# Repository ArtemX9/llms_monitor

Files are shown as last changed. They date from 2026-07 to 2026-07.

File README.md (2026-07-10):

# Claude Monitor

An ESP32-based desk display that shows real-time Claude Code and Grok API usage stats on a 320×240 ILI9341 TFT screen.

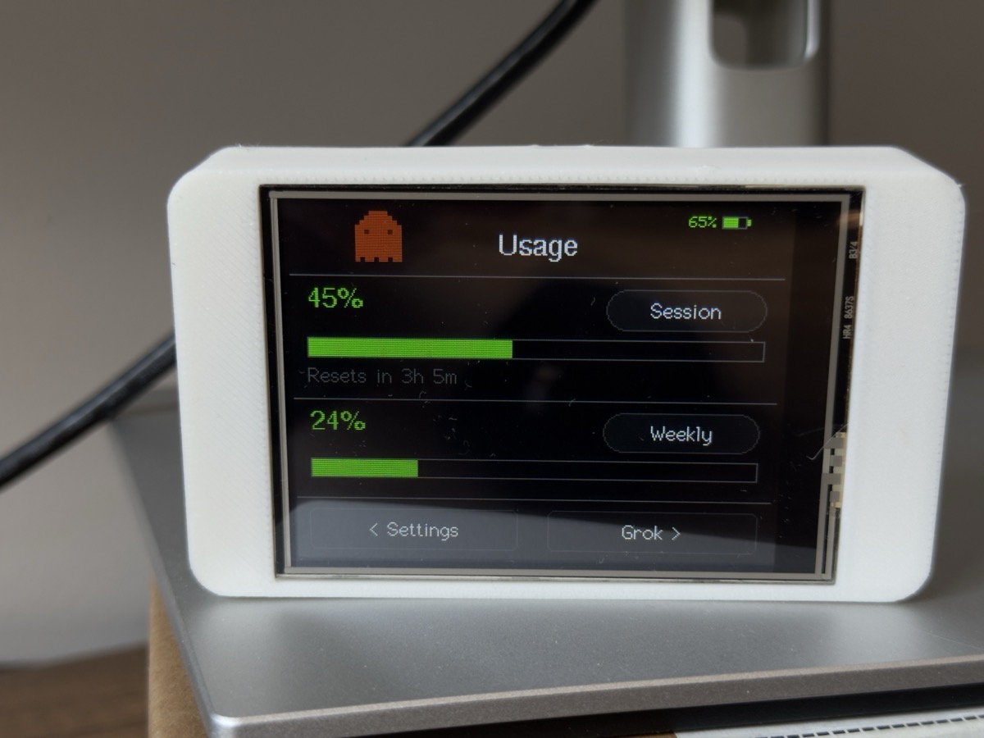
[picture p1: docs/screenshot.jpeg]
Device showing Claude Code session and weekly usage


## What it does

- **Claude screen** — session usage %, weekly usage %, and minutes until reset
- **Grok screen** — usage % and time until the billing period resets
- **Settings screen** — backlight brightness, refresh interval (30 / 60 / 120 s), reboot button
- Swipe left/right anywhere on the screen to navigate between the three screens
- Fetches data from a local proxy server over WiFi; auto-reconnects and restarts after 5 consecutive failures

## Hardware

| Component | Detail |
|---|---|
| MCU | ESP32 |
| Display | ILI9341 320×240 SPI TFT |
| Touch | XPT2046 resistive |
| Backlight | PWM-controlled via GPIO14 |

### Wiring

| Signal | GPIO |
|---|---|
| TFT CS | 15 |
| TFT DC | 21 |
| TFT RST | 4 |
| TFT MOSI | 23 |
| TFT SCLK | 18 |
| TFT MISO | 19 |
| Touch CS | 5 |
| Backlight | 14 |
| Status LED | 2 |

## Software

Built with [PlatformIO](https://platformio.org/) and the Arduino framework.

**Dependencies** (declared in `platformio.ini`, installed automatically):
- [TFT_eSPI](https://github.com/Bodmer/TFT_eSPI) — display + touch driver
- [ArduinoJson v7](https://arduinojson.org/) — JSON parsing

## Build & flash

```bash
pio run -t upload
pio device monitor       # 115200 baud
```

Prebuilt firmware binaries (for flashing with `esptool` instead of building from source) are published on the [Releases page](../../releases) for each tagged version.

## Data source

The device fetches from a local proxy server (default `http://192.168.2.131:3000`). The proxy should return:

```json
{
  "claude": { "session_pct": 43, "weekly_pct": 9, "reset_min": 240 },
  "grok":   { "usage_pct": 12, "reset_min": 44640 }
}
```

Note: on flat-rate Grok plans (e.g. X Premium), `usage_pct` reads `0` regardless of actual usage — the upstream billing endpoint only meters pay-as-you-go/on-demand usage, not flat-rate quota.

WiFi credentials and proxy URL are set at the top of `src/main.cpp`.

## Case (CAD)

```
cad/
  case.scad         — OpenSCAD source for the 3D-printed enclosure
  stl/
    case_body.stl    — exported body, ready to slice
    case_lid.stl      — exported lid, ready to slice
```

Edit `case.scad` in [OpenSCAD](https://openscad.org/) and re-export the STLs after any change.

## Project structure

```
src/
  Config.h          — pin and PWM channel defines
  Types.h           — UsageData, AppState, Event
  DataFetcher.h/cpp — WiFi management and HTTP fetch
  Renderer.h/cpp    — TFT drawing (pure, stateless)
  TouchRouter.h/cpp — touch input, returns Event enum
  main.cpp          — credentials, globals, setup(), loop()
```

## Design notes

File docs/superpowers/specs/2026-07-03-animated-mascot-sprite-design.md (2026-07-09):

# Animated mascot sprite — design

## Context

The Claude screen header currently blits a single static 10-col × 12-row pixel-art sprite
(`SPR` in `Renderer.cpp`) inline as part of `drawClaude()`. This design
replaces it with a small library of characters, each with a 4-frame idle animation, one of
which is randomly selected and shown at a time, re-rolled periodically. Two of the
characters additionally patrol back and forth across the header.

Scope: **Claude screen only.** The Grok screen keeps its current text-only header.

## Data format — `src/SpriteData.h`

Pure data, no logic. Same `0/1/2` grid convention as today (`0` = transparent, `1` = body
color, `2` = accent color) — one shared color pair for all characters (`body` = orange,
`dark` = darker orange, same values `drawClaude()` uses today).

Each character is 4 frames of a 12-row × 10-col `PROGMEM` grid, plus a movement type:

```cpp
enum class SpriteMotion { STATIC, PATROL };

struct Character {
  const uint8_t (*frames)[12][10]; // 4 frames
  SpriteMotion motion;
};
```

**Four characters for v1** (grids as previewed and approved in the visual companion
session):

1. **Bot** (today's sprite, reworked into an idle loop) — `STATIC`. Frames cycle
   eyes-open/neutral-smile → blink → eyes-open/wide-smile → eyes-open/neutral-smile.
2. **Ghost** — `PATROL`. Floaty body, wavy two-state tail alternating each frame.
3. **Cat** — `STATIC`. Pointy ears, blinking eyes (blink on frame 3 of 4).
4. **Robot** — `PATROL`. Single eye band that scans across 3 horizontal positions
   (center → left → center → right) over its 4 frames.

Adding a 5th character later means appending 4 grids + one `Character` table entry — no
other code changes.

## `src/AnimatedSprite.h/.cpp`

New class owning all animation state. Does **not** hold a `TFT_eSPI` reference — `draw()`
takes it as a parameter, so there's no constructor-order dependency with `Renderer` (unlike
`TouchRouter`, which does need to capture `renderer.tft()`).

```cpp
class AnimatedSprite {
public:
  void tick(unsigned long nowMs);      // advance frame/position; cheap no-op most calls
  bool needsRedraw() const;            // true if tick() changed frame or position since last draw()
  void draw(TFT_eSPI& tft);            // erase sprite lane + redraw at current frame/position
private:
  int _character;                      // current index into the character table
  int _frame;                          // 0-3
  unsigned long _lastFrameMs;
  unsigned long _lastRerollMs;
  enum class Phase { Idle, Entering, AtLeft, ToTitle, AtTitle, ToLeft } _phase;
  unsigned long _phaseStartMs;
  float _x;                            // current draw x
  void reroll(unsigned long nowMs);    // pick new random character via esp_random(), reset phase
};
```

### Timing constants

| Constant | Value | Notes |
|---|---|---|
| Frame rate (idle animation) | 4 fps (250 ms/frame) | applies to all characters, moving or not |
| Reroll interval | 5 min | `esp_random()`, no seeding needed on ESP32 |
| Entrance (off-screen → left spot) | 5 s, ease-in-out | `PATROL` characters only, plays once per reroll |
| Pause at each stop | 2 s | left spot and title spot |
| Travel leg (left ↔ title) | 3 s, ease-in-out | repeats forever after the one-time entrance |
| Resting/left x | 5 px (today's sprite position) | |
| Title-side x | tuned on hardware, ~90–100 px | must clear the "Usage" title's left edge — exact value picked during implementation by checking on the physical panel |
| Robot hop step size | ~6 px per step, alternating −3px y bounce | quantizes the eased position, doesn't change its own timing |

`STATIC` characters (Bot, Cat) skip all `Phase` states except `Idle`: `_x` is pinned to the
resting x for the character's whole lifetime; only the frame timer runs.

On reroll, `_phase` resets to `Entering` (for `PATROL`) or `Idle` (for `STATIC`) regardless
of whether the newly-picked character happens to match the previous one — no special-casing
for repeats.

## Redraw strategy

Every time `tick()` reports a change, `draw()`:
1. `fillRect(0, 0, 140, 44, TFT_BLACK)` — clears a fixed "sprite lane" spanning the header
   strip left of the "Usage" title. Cheap, and avoids tracking the previous frame's exact
   bounding box.
2. Blits the current character/frame's grid at `(_x, 2)`.

No `fillScreen()` — the rest of the header (title text, divider line) is never touched by
sprite ticks. Full-screen redraws still happen exactly where they do today (screen switch,
data fetch → `drawClaude()`), and `drawClaude()` calls `_sprite.draw()` once as part of its
existing full redraw.

## Integration

- `Renderer` gains `AnimatedSprite _sprite;` and a public `void tickSprite();`:
  ```cpp
  void Renderer::tickSprite() {
    _sprite.tick(millis());
    if (_sprite.needsRedraw()) _sprite.draw(_tft);
  }
  ```
- `drawClaude()` replaces its inline `SPR` blit loop with `_sprite.draw(_tft)`.
- `main.cpp`'s `loop()` calls `renderer.tickSprite()` unconditionally on every iteration
  when `state.screen == 0` — no external rate limiting needed, since `tick()` internally
  no-ops unless ~80ms have elapsed (settles to ~10Hz for position smoothness, independent
  of the 4fps frame rate and 5min reroll timer, both tracked by their own timestamps
  inside `AnimatedSprite`).
- This is a new, independent timer alongside the existing WiFi-fetch timer in `loop()` —
  it does not touch `state.needsFullRedraw` or the fetch cadence.

## Testing

No existing automated test harness in this repo (embedded/visual firmware). Verification
is manual, on the physical device after flashing: confirm each character's idle animation,
confirm Ghost/Robot patrol motion and pacing match what was approved in the visual
companion mockup, confirm reroll picks a new character every ~5 min, and confirm the
sprite lane redraw doesn't clip or flicker the "Usage" title.

## Out of scope (v1)

- Grok screen sprite/header (stays text-only).
- Per-character color variation (all characters share one body/accent color pair).
- More than 4 characters.
- Full off-screen exit-and-re-enter on every patrol cycle (only the very first appearance
  plays the off-screen entrance; subsequent cycles bounce between the left and title spots
  without leaving the screen).

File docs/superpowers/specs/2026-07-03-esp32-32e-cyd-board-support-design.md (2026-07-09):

# ESP32-32E CYD Board Support

## Goal

Add support for a second physical board — a "3.2 ESP32-32E 240x320 Resistance
Touch" all-in-one display module (Sunton/CYD-family clone; manufacturer
Shenzhen Hong Shu Yuan Technology; serial H06201; screen marked "HR4 8637S
B3/4") — on a dedicated branch, `esp32-32e-cyd`.

This board integrates the ESP32, TFT, and touch controller on one PCB with a
fixed pin layout, unlike the current hardware (a bare ILI9341 module
hand-wired to an ESP32 dev board on arbitrary pins).

## Hardware facts

Sourced from LCD Wiki's page for this exact board
(`3.2inch_ESP32-32E_Display`); to be verified empirically once flashed since
clone boards sometimes disagree with vendor docs.

| Function | Pin |
|---|---|
| TFT driver | **ST7789P3** (not ILI9341 — this is the main change) |
| TFT CS | IO15 |
| TFT DC | IO2 |
| TFT RST | EN (no dedicated GPIO — tied to chip reset) |
| TFT MOSI | IO13 |
| TFT SCLK | IO14 |
| TFT MISO | IO12 |
| TFT Backlight | IO27 (active high) |
| Touch (XPT2046) CS | IO33 |
| Touch IRQ | IO36 |
| Touch MOSI/SCLK/MISO | shared with TFT bus (13/14/12) |
| microSD CS/MOSI/SCLK/MISO | 5/23/18/19 (separate VSPI bus) — unused by this project, left unconfigured |

Two pins used by the current board's `Config.h` are unavailable here because
the display claims them:

- **GPIO2** — currently the status LED pin; on this board it's the TFT DC line.
- **GPIO14** — currently the backlight PWM pin; on this board it's the TFT SCLK line. The new board has its own dedicated backlight pin (IO27), so this isn't a "find a free pin" problem, just a different constant.

## Scope of changes (on the `esp32-32e-cyd` branch)

This branch is a direct hardware swap, not a multi-board codebase. No
`#ifdef`s, no second PlatformIO environment — `platformio.ini` and
`Config.h` are edited in place for this board, mirroring how the branch
itself already isolates the two hardware targets.

1. **`platformio.ini`**: replace `-DILI9341_DRIVER` and the old pin flags
   with `-DST7789_DRIVER` (or the exact TFT_eSPI macro name for ST7789P3)
   and the pin table above. `TFT_WIDTH`/`TFT_HEIGHT` stay 240×320. Rotation
   (currently `3` for landscape) and the touch-mirroring math documented in
   `CLAUDE.md` are specific to the old board's physical wiring and must be
   re-derived empirically on this board — not something to guess at in this
   design.

2. **`Config.h`**: drop `LED_PIN`. Change `TFT_BL_PIN` to 27.
   `BL_CHANNEL`/`BL_FREQ`/`BL_RES` unchanged.

3. **Replace the physical status LED with an on-screen indicator**, keeping
   the existing architecture's separation of concerns intact:
   - `DataFetcher::connect()` and `ensureWifi()` currently blink a GPIO
     directly inside their blocking wait loops. They will instead accept an
     optional tick callback (function pointer), invoked once per ~250ms
     blink tick and once more with the final connected/failed state.
     `DataFetcher` still does not touch the display or any drawing code —
     it only reports state through the callback.
   - `Renderer` gains a small method (e.g. `drawWifiIndicator(bool on)`)
     that draws or clears a small dot in a fixed screen corner without a
     full redraw.
   - `main.cpp` wires the two together: it passes a lambda to
     `DataFetcher` that calls `renderer.drawWifiIndicator(...)`, respecting
     the existing `ledEnabled` state.
   - The Settings screen's existing "LED" toggle (added in the most recent
     commit) is repointed to enable/disable this on-screen indicator instead
     of a physical GPIO. No UI relabeling needed — same toggle, same
     semantics from the user's point of view ("show a connection heartbeat
     indicator or not").

4. **`CLAUDE.md`**: once the board is flashed and the real rotation/touch
   quirks are known, add a short section documenting this board alongside
   the existing hardware-quirks section, so future work on this branch
   doesn't rediscover them.

## Out of scope

- No dual-board / shared-codebase support — this is a hardware-swap branch.
- No use of the onboard microSD slot, speaker, or I2C header — not needed by
  this project.
- Exact rotation value and touch-axis mirroring are left as "verify on
  hardware" — cannot be determined from docs alone, per this project's own
  documented experience with the current board's touch quirk.

## Testing / validation plan

After flashing to the physical board:

1. Confirm the display draws with correct colors and no inversion (ST7789
   panels frequently need a color-inversion flag that ILI9341 doesn't).
2. Confirm touch coordinates map correctly to visual positions on all
   screens; re-derive any mirroring math and update `TouchRouter.cpp` and
   `CLAUDE.md`.
3. Confirm backlight PWM works via GPIO27 across the brightness range.
4. Confirm the on-screen WiFi indicator behaves like the old LED did:
   blinks while connecting, solid when connected, off when disabled via the
   Settings toggle.

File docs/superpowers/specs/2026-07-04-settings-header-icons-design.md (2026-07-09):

# Settings screen: header icon buttons for Reboot and LED

## Problem

The Settings screen currently shows Reboot and LED-toggle as full-width labeled
cards in a body row (`drawOutlineCard` at y180-212, see
[Renderer.cpp:326-328](../../../src/Renderer.cpp#L326)). The goal is to move both
into small icon-only buttons in the header, freeing that body row, and to make
Reboot safer against accidental taps now that it sits right next to the title
rather than at arm's length at the bottom of the screen.

## Non-goals

- No change to Claude or Grok screens.
- No change to Brightness or Refresh cards' layout, coordinates, or behavior.
- No new `Event` enum value — `Event::Reboot` and `Event::ToggleLed` are reused;
  arm/confirm timing is `main.cpp`'s concern, not `TouchRouter`'s.
- No persistence of reboot-armed state across screen switches or reboots — it's
  transient UI state, reset to disarmed whenever the Settings screen isn't the
  active screen or the 2-second window lapses.

## Header layout

Header region is y=0 to y=44 (Brightness card starts at y=44, unchanged).

| Element | Position | Notes |
|---|---|---|
| Reboot icon button | `(6, 6, 32, 32)` rounded rect, radius 6 | Outline style: `colorCardBg()` fill, `colorDestructive()` border (normal state) |
| LED icon button | `(44, 6, 32, 32)` rounded rect, radius 6 | Filled bulb glyph, no separate border needed — the fill color itself is the state signal |
| "SETTINGS" title | `x=86, y=8` (was `x=10`) | Same `TITLE_FONT`, same y — only x moves to clear the icons |
| WiFi status dot | `(310, 8)` | Unchanged |

Gap between the two icon buttons: 6px+32px=38, +6px gap = LED starts at x=44. Both fit comfortably before the title at x=86.

## Icon glyphs

Both drawn from `TFT_eSPI` primitives — no icon font or image assets.

**Reboot (refresh/restart glyph):** a broken ring drawn with `_tft.drawArc(cx, cy, r, ir, startAngle, endAngle, fgColor, bgColor, true)` spanning roughly 270° (e.g. 45°→315°, leaving a 90° gap), plus a small filled triangle arrowhead at the arc's leading end (`_tft.fillTriangle(...)`, three points computed from the end angle) to imply direction. Center at the button's center `(22, 22)` relative to button origin, i.e. absolute `(6+16, 6+16) = (22, 22)`; ring radius `r=9`, inner radius `ir=6` (3px-thick ring, comfortably legible at this size).

- Normal (disarmed) state: button background `colorCardBg()`, border `colorDestructive()`, glyph drawn in `colorDestructive()`.
- Armed state (after first tap): button background fills solid `colorDestructive()` (no border needed), glyph redrawn in a contrasting color (`TFT_WHITE`) so it stays visible against the red fill.

**LED (lamp glyph):** a simple bulb shape — a filled circle (the bulb's glass) plus a small filled rectangle beneath it (the base/screw), both drawn in the same single fill color representing state, no separate dot:
- On: `colorLedOn()` — new helper, `color565(34, 197, 94)` (matches the mockup's green, distinct from the general UI accent indigo since this is a literal on/off traffic-light signal, not a "selected" state)
- Off: `colorDestructive()` (red) — reusing the existing destructive-red helper since both represent "off"/negative state colors in this palette

Bulb circle: center `(22, 22)` relative to button origin (absolute `(62, 22)`), radius 8. Base rectangle: `4px` wide, `3px` tall, centered below the circle.

## Body layout after removing the old LED+Reboot row

- Brightness card: unchanged, `drawCard(6, 44, 308, 56)`.
- Refresh card: unchanged, `drawCard(6, 110, 308, 58)`.
- The old row at y180-212 (`drawLedToggle` + the Reboot `drawOutlineCard` call in `drawSettings`) is deleted entirely. The vertical space from y=168 (Refresh card's bottom edge) to the nav buttons' new top edge (y=209, see below) is simply empty — no new element fills it.

## Nav buttons resize

`< Grok` / `Claude >` (`drawButton` calls in `drawSettings`, currently `(8, 216, 142, 22)` and `(170, 216, 142, 22)`):

- Width stays `142` (already uses 304 of the 320px screen width across both buttons; ×1.3 would overflow off-screen).
- Height scales ×1.3: `22 → 29`.
- New y: `209` (was `216`) — keeps the same ~2px bottom margin as before (`209+29=238`, screen height is 240, same bottom margin the old buttons had at `216+22=238`).
- New calls: `drawButton(8, 209, 142, 29, "< Grok", f, b, TFT_WHITE)` and `drawButton(170, 209, 142, 29, "Claude >", f, b, TFT_WHITE)`.

This is the *only* change to Claude/Grok-shared code in this spec — `drawButton`'s signature and body are untouched; only the call-site arguments in `drawSettings` change.

## Reboot confirm-tap mechanics

New `AppState` field: `unsigned long rebootArmedAt = 0;` (`0` means disarmed), declared alongside the struct's other fields in [Types.h](../../../src/Types.h#L14), owned exclusively by `loop()` per existing convention.

Flow, entirely in `main.cpp`'s `loop()`:

1. Tap on the reboot icon always emits `Event::Reboot` (no new `Event` value).
2. On `Event::Reboot`:
   - If `state.rebootArmedAt != 0 && millis() - state.rebootArmedAt < 2000`: this is the confirming second tap — proceed exactly as today (`renderer.showRebooting(); delay(300); ESP.restart();`).
   - Else: this is the arming first tap — set `state.rebootArmedAt = millis();` and call a new `renderer.updateRebootIcon(true)` to redraw the icon in its armed (solid red) visual.
3. Every `loop()` iteration, if `state.screen == 2 && state.rebootArmedAt != 0 && millis() - state.rebootArmedAt > 2000`: auto-disarm — set `state.rebootArmedAt = 0;` and call `renderer.updateRebootIcon(false)` to revert the icon to its normal outline visual.
4. On `Event::NavForward`/`Event::NavBack` while `state.screen == 2` (i.e. leaving Settings): reset `state.rebootArmedAt = 0;` silently — no redraw call needed since `switchTo()` already does a full redraw of the destination screen.

No debounce changes needed in `TouchRouter` — its existing 300ms `_lastTouch` debounce (unrelated to this 2-second arm window) continues to work exactly as today; the two taps needed to confirm a reboot are two separate, individually-debounced touch events.

## TouchRouter changes

Two new zones added to `TouchRouter::poll()`'s `screen == 2` branch, checked before the existing zones (they occupy y=6-38, below any other zone's range):

```cpp
if (y >= 6 && y <= 38) {
  if (x >= 6  && x <= 38) return Event::Reboot;
  if (x >= 44 && x <= 76) return Event::ToggleLed;
  return Event::None;
}
```

The old zone check for the y180-212 row (LED at x10-155, Reboot at x165-310) is deleted entirely — that row no longer has any controls.

The nav-row check moves from `y > 213` to `y > 204` (buffer above the new button top edge at y=209; still well below the Refresh card's bottom edge at y=168 and the interval buttons' zone which ends at y=162, so no ambiguity with the now-empty gap between them).

## Renderer changes

- `drawSettings`: header title x moves to 86; calls a new private `drawRebootIcon(false)` and a rewritten `drawLedToggle(ledEnabled)` (now draws the icon button, not the old text card) at their header positions instead of the old body-row `drawOutlineCard`/`drawLedToggle` calls; nav button calls updated to the new y=209, h=29 coordinates.
- New private `void drawRebootIcon(bool armed)` — draws the button background/border per the armed/disarmed states above, plus the arc+arrowhead glyph.
- New public `void updateRebootIcon(bool armed)` — thin wrapper calling `drawRebootIcon(armed)`, mirroring the existing `updateLedToggle` pattern (declared in `Renderer.h`'s public section alongside `updateLedToggle`).
- `drawLedToggle(bool ledEnabled)` rewritten to draw the bulb glyph (filled circle + base rect) at its new header position and size, using `colorLedOn()`/`colorDestructive()` instead of the old outline-card-with-text approach. Its existing public wrapper `updateLedToggle` needs no signature change — it already just calls `drawLedToggle`.
- New private `uint16_t colorLedOn()` color helper alongside the existing `colorAccent()`/`colorDestructive()`/etc. in the "Shadcn-style palette" block.
- `drawOutlineCard` (added for the previous restyle) becomes unused by `drawSettings` once this change lands. It's still a generically useful helper (rounded card + centered label) — leaving it in place is fine (YAGNI cuts against inventing a reason to delete a small, still-coherent, still-compiling helper it just isn't used by anymore, not against harmless unused code); if a future task never finds a use for it, removing it then is a one-line cleanup, not a design concern for this spec.

## Files changed

- `src/Types.h` — add `rebootArmedAt` field to `AppState`.
- `src/TouchRouter.cpp` — add header icon zones, remove old y180-212 zone, adjust nav-row y threshold.
- `src/Renderer.h` — add `updateRebootIcon` to the public section, `drawRebootIcon` and `colorLedOn` to the private section.
- `src/Renderer.cpp` — all drawing changes described above.
- `src/main.cpp` — reboot arm/confirm/auto-disarm logic in `loop()`.

No changes to `src/DataFetcher.*`, `src/AnimatedSprite.*`, `src/SpriteData.h`, `src/Config.h`, or the Claude/Grok screens beyond the shared `drawButton` call-site coordinate change already covered above.

## Testing

Same as the prior restyle work — no automated test harness exists for `Renderer`
or hardware touch/timing behavior. Verification is `pio run` compiling cleanly,
then hardware flash + manual verification:

- Both header icons render at the correct position/size, don't visually collide
  with the shifted title or the WiFi dot.
- Tapping the LED icon toggles it on/off exactly as before (just via the new
  icon instead of the old text card), with the bulb filling green/red correctly.
- Tapping the reboot icon once arms it (fills solid red); tapping it again
  within 2 seconds actually reboots the device; waiting past 2 seconds without
  a second tap reverts it to the normal outline automatically.
- Navigating away from Settings while armed and back again shows the icon
  disarmed (normal outline), not stuck in the armed state.
- Nav buttons (`< Grok` / `Claude >`) are visibly taller and still register
  taps correctly across their full new height.
- The empty space where the old LED+Reboot row was doesn't respond to taps
  (falls through to `Event::None`).

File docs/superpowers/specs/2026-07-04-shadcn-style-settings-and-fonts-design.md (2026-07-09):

# Shadcn-style Settings restyle + consistent fonts across all screens

## Problem

The Settings screen (`Renderer::drawSettings`, [Renderer.cpp:240-296](../../../src/Renderer.cpp#L240)) uses
bright, saturated semantic colors (`TFT_GREEN`, `TFT_YELLOW`, `TFT_RED`, `TFT_CYAN`) and plain
square outlines (`drawRect`/`drawFastHLine` dividers) — a much rougher look than the rounded,
neutral-grey nav buttons already used at the bottom of every screen (`drawButton`,
[Renderer.cpp:43](../../../src/Renderer.cpp#L43)).

Separately, only the Claude screen's "Usage" header uses the vendored vector font
(`FreeSansBold12pt7b`, `TITLE_FONT` at [Renderer.cpp:3](../../../src/Renderer.cpp#L3)) — every
other title, label, and number on all three screens uses TFT_eSPI's blocky built-in GLCD fonts
(font 2 / font 4).

Goal: make Settings visually resemble a Shadcn UI component set (neutral dark cards, one muted
accent color, rounded corners), and make font usage consistent across Claude, Grok, and Settings.

## Non-goals

- No change to touch hit-box coordinates in `TouchRouter.cpp` — all touch zones stay exactly
  where they are today.
- No change to the bottom nav buttons' existing style (`< Grok` / `Claude >` / `< Settings` /
  `Grok >`) — they're already neutral-grey rounded rects and are the reference point the rest of
  the UI is matching.
- No change to `AnimatedSprite`/mascot rendering.
- No change to data/fetch logic, WiFi, or any non-Renderer code.

## Color palette

Replaces bright semantic colors on the Settings screen only (Claude/Grok progress-bar colors via
`progressColor()` are unrelated status indicators and are out of scope):

| Role | Value | Replaces |
|---|---|---|
| Screen background | `color565(8,8,10)` | `TFT_BLACK` |
| Card background | `color565(24,24,27)` | (new — cards didn't exist before) |
| Card border (default) | `color565(63,63,70)` | `TFT_DARKGREY` |
| Accent (selected/active/focus) | `color565(99,102,241)` | `TFT_GREEN` / `TFT_YELLOW` |
| Label / caption text | `color565(140,140,145)` | `TFT_CYAN` |
| Primary value text | `TFT_WHITE` | unchanged |
| Destructive (Reboot) | `color565(220,38,38)` | `TFT_RED` |

## Settings layout: cards instead of dividers

Each control group becomes its own rounded-rect card (radius 6, matching `drawButton`'s existing
radius) drawn at the *same outer pixel footprint* the section already occupies, so
`TouchRouter::poll()`'s hit-boxes ([TouchRouter.cpp:18-36](../../../src/TouchRouter.cpp#L18))
need no changes:

1. **Brightness card** — spans the label + `−`/bar/`+` row. Bar fill and both buttons switch to
   accent indigo fill on interaction; card border uses the default border color.
2. **Refresh card** — spans label + 3 interval buttons. Selected interval gets an accent border
   + accent text instead of green.
3. **LED toggle card** and **Reboot card** — same footprint as today, side by side; LED uses
   accent border+text when on, default border+grey text when off; Reboot uses the destructive
   red border+text (outline style, not solid fill — consistent with the other outline-style
   cards).

`drawFastHLine` section dividers are removed; the card borders themselves separate sections.

The three partial-update functions (`updateBrightnessBar`, `updateIntervalButtons`,
`updateLedToggle`) keep redrawing only their existing fixed pixel rectangle — same
single-pass-redraw discipline already used elsewhere in this codebase (see CLAUDE.md's note on
this board's lack of double buffering); no new flicker risk is introduced since nothing here is a
fast-repeating redraw.

## Font consistency (all three screens)

Three roles, using the vendored GFXFF free fonts already available under
`lib/TFT_eSPI/Fonts/GFXFF/`:

| Role | Font | Replaces | Used for |
|---|---|---|---|
| Title | `FreeSansBold12pt7b` (already used on Claude) | GLCD font 4 | "Usage", "GROK BUILD", "SETTINGS" |
| Value | `FreeSansBold18pt7b` | GLCD font 4 | Big percentages, Grok token/request numbers, Settings `−`/`+`, REBOOT, LED ON/OFF |
| Label | `FreeSans9pt7b` | GLCD font 2 | Pill text, reset-time caption, Tokens/Requests labels, Settings section labels, interval buttons, bottom nav buttons |

Mechanics:
- Replace `drawString(str, x, y, N)` (GLCD font-number form) with `setFreeFont(&FONT)` +
  `drawString(str, x, y)`, followed by `setTextFont(1)` to restore the default GLCD font for any
  code path that doesn't immediately set another free font next.
- Every centered string (`MC_DATUM`) needs no position changes — centering is computed from
  actual rendered width regardless of font metrics.
- Fixed-position (`TL_DATUM`) strings — percentages, titles, section labels — keep their current
  x/y anchors. All current strings are short relative to their allotted space, so proportional
  font width (vs. GLCD's fixed width) is not expected to cause overlap or clipping, but this
  should be visually confirmed on hardware once implemented (see Testing).
- Touches: `drawClaude`, `updateClaude`, `drawGrok`, `updateGrok`, `drawSettings`,
  `updateBrightnessBar`, `updateIntervalButtons`, `drawLedToggle`, `drawButton`, `drawPill`.

## Files changed

- `src/Renderer.cpp` — all drawing/color/font changes described above.
- `src/Renderer.h` — only if new color or font constants need declaring at class/file scope
  (likely just `#define`s near the top of `Renderer.cpp`, same pattern as the existing
  `TITLE_FONT`).

No changes to `TouchRouter.cpp`, `TouchRouter.h`, `main.cpp`, `Types.h`, `Config.h`,
`DataFetcher.*`, `AnimatedSprite.*`, or `SpriteData.h`.

## Testing

This is a pure rendering change with no unit-testable logic (no test harness exists for
`Renderer` — it's hardware-drawing code). Verification is visual, on the actual ESP32-32E CYD
hardware:

- Flash and check all three screens (Claude, Grok, Settings) for correct colors, rounded card
  borders, and font rendering with no clipped/overlapping text.
- Exercise every Settings touch control (brightness −/+, all 3 interval buttons, LED toggle,
  Reboot, both nav buttons) to confirm hit-boxes still line up with the restyled (but
  same-footprint) visuals.
- Confirm partial updates (brightness drag, interval tap, LED toggle) redraw cleanly with no
  visible artifacts, matching the existing "diff-only redraw" discipline.

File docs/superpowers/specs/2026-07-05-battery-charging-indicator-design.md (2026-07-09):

# Battery charging indicator (software voltage-trend heuristic)

## Problem

The battery level indicator (already shipped) shows charge percentage but not
whether the battery is currently charging. The board gives no clean hardware
signal for this — see "Why no hardware signal" below — so this adds a
software-only approximation: infer "charging" from whether recent battery
voltage readings are trending up.

## Why no hardware signal exists (recap from design discussion)

Checked the full ESP32-WROOM-32E main control circuit schematic (vendor
manual, Figure 3.10): every net wired to a GPIO is explicitly listed, and
neither the TP4054's `CHRG` status pin nor the board's `+5V`/`VCC5V` rail
(which would indicate "USB present") appears anywhere in that list. Both are
genuinely unrouted to the microcontroller on this board — not a software gap,
a wiring one. The only path to *real* charging detection is a hardware
modification (bodge `CHRG` to a spare GPIO like `IO35`/`IO39`), which is out
of scope for this feature — this spec is the software-only fallback.

## Non-goals

- No hardware modification (see above) — this is the deliberately-approximate
  software path, chosen after that alternative was discussed and declined.
- No attempt to distinguish "fully charged, charger stopped" from "still
  slowly topping off (CV taper)" — the algorithm is intentionally sticky
  through flat readings (see below), which means it will show "charging" for
  a while after the charger has effectively finished, and there is no fix for
  this without current sensing (which this board doesn't have either).
- No change to the existing battery-level color logic (`TFT_GREEN`/
  `colorDestructive()` by `BAT_LOW_PCT`) — charging state is drawn as an
  overlay glyph, layered independently on top of whatever color the level
  logic already picked, so the two concerns don't interact.
- No new files — this extends the existing `Battery`/`Renderer`/`main.cpp`
  trio from the battery-level feature.

## Detection algorithm

Lives entirely in `Battery`, since it's derived from the same voltage samples
that class already collects — `Renderer` and `main.cpp` only ever see the
resulting bool, never raw mV or streak state (SRP, same boundary as the level
feature).

Each new averaged mV reading is compared to the previous one and classified
into three buckets using a noise-floor threshold, `BAT_CHG_RISE_MV` (15mV —
comfortably above this ADC's jitter even after `BAT_SAMPLE_COUNT`-sample
averaging, per the existing `readPercent()` averaging loop):

- **Rising**: `delta > +BAT_CHG_RISE_MV`
- **Falling**: `delta < -BAT_CHG_RISE_MV`
- **Flat**: everything in between

State machine (two streak counters, both reset by any non-matching sample —
i.e. streaks must be *consecutive*, not just "N rising samples somewhere in
history"):

- Enter `_charging = true` after `BAT_CHG_RISE_STREAK` (3) consecutive
  Rising samples. A Flat or Falling sample resets the rising streak to 0.
- Once charging, a Flat sample does **not** change `_charging` and does not
  count toward the falling streak (this is what keeps the indicator alive
  through the CV taper instead of flapping off as voltage flattens near
  full charge) — it does still reset the falling streak to 0, so exit
  requires a genuinely consecutive decline.
- Exit `_charging = false` after `BAT_CHG_FALL_STREAK` (2) consecutive
  Falling samples.
- The very first reading ever (no previous mV to diff against, tracked via
  a `_lastMv = -1` sentinel) skips classification entirely — `_charging`
  starts `false`.

This means ordinary discharge can never falsely *trigger* charging (a
declining or flat-under-load battery cannot produce 3 consecutive clear
rises), and a real unplug-while-charging reliably exits within 2 fetch
intervals once the battery starts actually dropping under the display's own
load.

### `Config.h` additions

```cpp
#define BAT_CHG_RISE_MV     15  // mV delta beyond which a reading counts as "rising"/"falling" (else "flat")
#define BAT_CHG_RISE_STREAK 3   // consecutive rising reads required to enter "charging"
#define BAT_CHG_FALL_STREAK 2   // consecutive falling reads required to exit "charging"
```

### `Battery.h` / `Battery.cpp` changes

Public surface grows by exactly one method — `readPercent()`'s signature and
behavior are unchanged:

```cpp
class Battery {
public:
  void init();
  int  readPercent();       // unchanged signature; now also updates charging state as a side effect
  bool isCharging() const;  // new — reflects state as of the last readPercent() call

private:
  int  readMilliVoltsAveraged(); // the existing averaging loop, factored out (used once per readPercent() call — no double-sampling)
  void classify(int mv);         // the three-bucket streak logic above

  int  _lastMv        = -1;
  int  _risingStreak  = 0;
  int  _fallingStreak = 0;
  bool _charging      = false;
};
```

```cpp
int Battery::readMilliVoltsAveraged() {
  uint32_t sum = 0;
  for (int i = 0; i < BAT_SAMPLE_COUNT; i++) {
    sum += analogRead(BAT_ADC_PIN);
    delayMicroseconds(100);
  }
  uint32_t raw = sum / BAT_SAMPLE_COUNT;
  return esp_adc_cal_raw_to_voltage(raw, &s_adcChars) * 2;
}

void Battery::classify(int mv) {
  if (_lastMv >= 0) {
    int delta = mv - _lastMv;
    if (delta > BAT_CHG_RISE_MV) {
      _risingStreak++;
      _fallingStreak = 0;
      if (_risingStreak >= BAT_CHG_RISE_STREAK) _charging = true;
    } else if (delta < -BAT_CHG_RISE_MV) {
      _fallingStreak++;
      _risingStreak = 0;
      if (_fallingStreak >= BAT_CHG_FALL_STREAK) _charging = false;
    } else {
      // Flat: sticky through CV taper — don't touch _charging, but a flat
      // sample isn't part of either streak, so it resets both.
      _risingStreak = 0;
      _fallingStreak = 0;
    }
  }
  _lastMv = mv;
}

int Battery::readPercent() {
  int mv = readMilliVoltsAveraged();
  classify(mv);
  if (mv <= BAT_MIN_MV) return 0;
  if (mv >= BAT_MAX_MV) return 100;
  return (mv - BAT_MIN_MV) * 100 / (BAT_MAX_MV - BAT_MIN_MV);
}

bool Battery::isCharging() const { return _charging; }
```

## Icon rendering

`drawBatteryIcon(int pct)` becomes `drawBatteryIcon(int pct, bool charging)`.
When `charging` is true, a small 2-segment lightning-bolt glyph is drawn in
`TFT_WHITE` inside the body's interior box (after the existing
`drawProgressBar` + nub calls) — same convention as the reboot icon's armed
state, which also draws a white glyph over a colored fill for contrast
against either color. This keeps the level-color logic (green/red by
`BAT_LOW_PCT`) completely untouched; charging is a layered overlay, not a
color change, so a low, charging battery still reads as both "low" (red-ish
body) and "charging" (white bolt) simultaneously. Note the bolt sits over
whatever `drawProgressBar` already painted at that x-range — the colored
fill only at higher percentages, the black unfilled remainder at lower
ones (e.g. plugging in a nearly-dead pack) — white reads clearly against
either, so this doesn't need special-casing, just don't read "on top of the
fill" as implying the fill is always there under it.

```cpp
void Renderer::drawBatteryIcon(int pct, bool charging) {
  if (pct < 0)   pct = 0;
  if (pct > 100) pct = 100;
  uint16_t color = (pct > BAT_LOW_PCT) ? TFT_GREEN : colorDestructive();

  _tft.fillRect(_tft.width() - 72, 2, 50, 12, TFT_BLACK);

  char buf[6];
  snprintf(buf, sizeof(buf), "%d%%", pct);
  _tft.setTextFont(1);
  _tft.setTextColor(color);
  _tft.setTextDatum(MR_DATUM);
  _tft.drawString(buf, _tft.width() - 45, 8);
  _tft.setTextFont(0);
  _tft.setTextDatum(TL_DATUM);

  drawProgressBar(_tft.width() - 42, 4, 16, 8, pct, color);
  _tft.fillRect(_tft.width() - 26, 6, 2, 4, color); // nub

  if (charging) {
    int bx = _tft.width() - 42; // body's left edge, matches drawProgressBar's x above
    _tft.drawLine(bx + 9, 5,  bx + 6, 8,  TFT_WHITE);
    _tft.drawLine(bx + 6, 8,  bx + 10, 10, TFT_WHITE);
  }
}
```

`drawProgressBar`'s border occupies the body rect's outermost row on each
edge (`_tft.drawRect(bx, 4, 16, 8, ...)` outlines rows `y=4` and `y=11`;
the fill interior is `fillRect(bx+1, 5, ..., 6, ...)`, i.e. rows `y=5..10`).
The bolt's points (`y=5,8,10`) are chosen to stay entirely within that
`5..10` interior band, not touch the border rows — an earlier draft placed
the bottom point at `y=11` (on the border) before this was caught in
self-review.

Both line segments stay within the existing body footprint (`x: bx+6..bx+10`,
`y: 5..10`) — no change to the icon's overall bounding box, so none of the
six screens' collision clearances (including the flagged, hardware-verified
portrait-Settings risk from the level-indicator spec) are reopened.

`Renderer.h` gains `bool _batteryCharging = false;` next to `_batteryPct`,
and `setBattery`'s signature changes to match:

```cpp
void Renderer::setBattery(int pct, bool charging) {
  _batteryPct = pct;
  _batteryCharging = charging;
  drawBatteryIcon(_batteryPct, _batteryCharging);
}
```

Each of the six existing draw functions' `drawBatteryIcon(_batteryPct);`
call becomes `drawBatteryIcon(_batteryPct, _batteryCharging);` — one word
added per call site, same six locations as the level-indicator feature
(`drawClaude`, `drawClaudePortrait`, `drawGrok`, `drawGrokPortrait`,
`drawSettings`, `drawSettingsPortrait`).

## `main.cpp` integration

Both existing call sites change from a single-expression call to two
statements — **this ordering is required, not stylistic**: C++ does not
guarantee left-to-right evaluation of a function's argument expressions, so
writing `renderer.setBattery(battery.readPercent(), battery.isCharging())`
as one expression risks `isCharging()` evaluating before `readPercent()`
updates the streak state, silently reading last cycle's charging flag
instead of this one's. Splitting into two statements removes the ambiguity:

In `setup()` (replacing the existing single-line call):
```cpp
  battery.init();
  int pct = battery.readPercent();
  renderer.setBattery(pct, battery.isCharging());
```

In `loop()`'s existing fetch-interval block (replacing the existing
single-line call):
```cpp
  if (millis() - lastFetch > state.fetchInterval) {
    int pct = battery.readPercent();
    renderer.setBattery(pct, battery.isCharging());
    if (fetcher.fetch(data)) {
```

## Files changed

- `src/Config.h` — three new constants.
- `src/Battery.h`, `src/Battery.cpp` — `isCharging()`, internal streak state,
  `readMilliVoltsAveraged()`/`classify()` factored out of `readPercent()`.
- `src/Renderer.h` — `_batteryCharging` member; `drawBatteryIcon`/
  `setBattery` signatures gain the `bool charging` parameter.
- `src/Renderer.cpp` — bolt-drawing addition in `drawBatteryIcon`; `charging`
  threaded through `setBattery`; six call-site updates.
- `src/main.cpp` — both `setBattery` call sites split into two statements
  per the evaluation-order note above.

No new files, no changes to `Types.h`, `TouchRouter.*`, `DataFetcher.*`,
`AnimatedSprite.*`, `NvsConfig.*` — charging state is transient, Battery/
Renderer-owned only, same as the level percentage.

## Testing

No automated test harness exists for this embedded project. Verification is
`pio run` compiling cleanly, then hardware checks with the battery connected:

- Plug in USB-C while running on battery: bolt appears within a few fetch
  intervals (not instantly — this is inherent to requiring 3 consecutive
  rising reads, already disclosed as a tradeoff).
- Bolt renders correctly layered on top of both a green (charged) and red
  (low-battery) body fill.
- Unplug USB-C while the bolt is showing: bolt disappears within roughly 2
  fetch intervals of the battery visibly starting to discharge under load.
- Leave it charging until the battery reaches ~100%: confirm the known,
  accepted limitation — the bolt is expected to keep showing for a while
  into the CV-taper flat period, not disappear the instant charging
  current tapers off.
- No new collision with the WiFi dot, titles, sprite, or Settings header
  icons introduced — bolt stays within the existing icon footprint, so this
  should be a no-op check, but confirm on at least one screen since it's a
  new visual element.
- `BAT_CHG_RISE_MV` (15mV) and the streak counts (3/2) are reasoned
  estimates, not yet measured against this specific board's real ADC noise
  floor — this project's level-indicator feature has its own hardware
  verification pass still pending as of this writing, so there's no
  existing on-device noise data to base these on. If the bolt flickers
  on/off during a real charge session (a sign the threshold is too tight
  for actual sample-to-sample jitter) or never triggers despite visibly
  charging (too loose, or classification working but streak requirement
  too strict for the chosen fetch interval), retune `BAT_CHG_RISE_MV`/
  `BAT_CHG_RISE_STREAK`/`BAT_CHG_FALL_STREAK` in `Config.h` — no code
  changes needed elsewhere, they're isolated constants.
- A momentary bad reading (e.g. a loose battery connector glitching to a
  near-zero raw value for one sample) followed by a normal reading would
  produce a large spurious "rising" delta, contributing one count toward
  the rising streak. This is the same class of accepted limitation as the
  floating-pin note from the level-indicator feature's final review — not
  a regression, just worth knowing if the bolt ever flickers on right after
  a physical jostle of the connector rather than an actual USB plug-in.

### Hardware verification outcome (2026-07-05)

Tested on the real board (LP405090 connected to JP2, charged from both a
MacBook Pro's USB-C port and a phone/tablet powerbank). Findings:

- The battery-level reading itself behaves correctly and as physically
  expected: resting (no USB) read ~47%; under either charger the reading
  rose to ~60-65% and settled there, then reverted to ~47% within moments
  of disconnecting. This is normal Li-ion behavior (terminal voltage under
  charge current sits above true resting state-of-charge due to internal
  resistance) — not a bug, and it confirms the ADC/divider path is sound.
- The charging bolt did **not** reliably appear. Temporary diagnostic
  logging (added and removed during this investigation, never committed)
  showed why: at this board's charge rate and the user's 120s fetch
  interval, real consecutive-reading deltas were only 0-4mV. Two problems
  compound: (1) `esp_adc_cal_raw_to_voltage()` returns 1mV resolution,
  doubled by the divider math to 2mV steps, so most individual ticks read
  `delta=0` purely from quantization, not noise; (2) the occasional
  non-zero jumps (+2/+4mV) were never *consecutive* — there were always
  zero-delta ticks between them — so `BAT_CHG_RISE_STREAK`'s requirement
  of 3 **consecutive** rising reads structurally cannot be satisfied by
  data shaped like this, regardless of how low `BAT_CHG_RISE_MV` is set.
- One retuning pass was applied based on this data (`BAT_SAMPLE_COUNT`
  8→32 to reduce ADC noise, `BAT_CHG_RISE_MV` 15→4 to match the observed
  rate) — a genuine improvement over the original untested guess, but it
  does not fix the structural consecutive-tick problem above.
- The real fix would be comparing each reading against one from several
  ticks further back (e.g. 5 ticks ≈ 10 minutes at this interval) instead
  of only the immediately-previous reading, so real accumulated drift
  becomes distinguishable from single-step quantization — a materially
  bigger design change (needs a small rolling history, not just
  `_lastMv`). **Decided not to pursue this** — the feature is accepted as
  a best-effort approximation with this known gap: the bolt may fail to
  appear during slow or near-full charging even though charging is
  genuinely happening. Documented in `Config.h` alongside the constants.

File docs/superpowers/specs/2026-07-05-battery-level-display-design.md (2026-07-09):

# LP405090 battery support: hardware wiring + on-screen battery level

## Problem

The board has a battery connector (JP2), a TP4054 Li-ion charge/discharge
circuit, and a battery-voltage ADC divider already built in — none of it is
used yet. The goal is to connect an LP405090 (3.7V, 1800mAh) pack and show its
charge level as a small persistent indicator on every screen.

## Non-goals

- No charging-state detection ("is USB plugged in / is it charging"). The
  board's design gives no clean software signal for this: `BAT_ADC` (GPIO34)
  reads the raw battery-node voltage through a fixed divider regardless of
  whether the TP4054 is actively charging it or the discharge FET (Q3) is
  supplying the board from it, and there is no separate "USB present" GPIO
  broken out. Inferring it from voltage trends would need debouncing/hysteresis
  well beyond what a simple level readout needs — out of scope here.
- No icon blinking / animation for the low-battery warning — a static color
  change at the threshold, per the earlier design discussion.
- No coulomb counting, no discharge-curve lookup table — a single linear
  mV→% map, same category of approximation the vendor's own demo sketch uses,
  just with a more realistic 0%/100% floor/ceiling (see below).
- No changes to `AnimatedSprite`, `DataFetcher`, `TouchRouter`, or the
  Claude/Grok/Settings body layouts — this only adds one small corner widget
  to each screen's existing header.

## Hardware wiring (no firmware involved)

- JP2 is a 2-pin, **1.25mm-pitch** header (`BAT+` / `GND`), feeding the
  onboard TP4054 charge IC directly — no external charge circuitry needed.
- ⚠️ LP405090 packs commonly ship with a 2-pin **JST-PH (2.0mm pitch)**
  connector. Check the pack's actual plug against JP2 before connecting — if
  the pitch doesn't match, either source/rewire a 1.25mm-pitch JST plug for
  the pack, or use a 2.0mm→1.25mm adapter. Do not force a mismatched
  connector onto the header.
- ⚠️ **Verify polarity against the PCB's own `+`/`-` silkscreen at JP2**
  before plugging in. This isn't confirmable from the vendor PDF text alone,
  and reversing it can damage the TP4054 circuit.
- Charging current is fixed by the board's R27 (500mA max) — nothing to
  configure in firmware.

## ADC reading

Confirmed from both the schematic ("Battery level detection circuit") and the
vendor's own `13_Get_Battery_Voltage` demo sketch:

- `BAT_ADC` is GPIO34, fed by a 100K/100K divider off `BAT+` (exactly 2:1).
- Read via `analogRead(34)` + `esp_adc_cal_raw_to_voltage()`, then **×2** to
  undo the divider — matches the vendor demo exactly, which is the
  known-working reference for this exact board (see the `User_Setup.h`
  lesson in `CLAUDE.md` about trusting vendor-verified specifics over
  assumptions on this hardware).
- Mapping to percent: the vendor demo uses 2500mV(0%)–4200mV(100%), but
  2500mV is an undervoltage-cutoff sentinel, not a meaningful "empty"
  point for a single-cell LiPo. This design uses **3300mV(0%)–4200mV(100%)**
  instead — a standard, simple linear approximation for a single-cell
  Li-ion/LiPo without a fuel-gauge IC.

## `Config.h` additions

```cpp
#define BAT_ADC_PIN      34
#define BAT_SAMPLE_COUNT 8     // averaged per reading, matches ADC noise-reduction practice
#define BAT_MIN_MV       3300  // maps to 0%
#define BAT_MAX_MV       4200  // maps to 100%
#define BAT_LOW_PCT      15    // battery icon renders red at/below this
```

## New `Battery.h` / `Battery.cpp`

A single-responsibility module, following the project's existing
one-concern-per-file convention (`DataFetcher` owns WiFi, `Renderer` owns
drawing, `Battery` owns ADC→percent — nothing else touches the ADC).

```cpp
class Battery {
public:
  void init();        // characterizes the ADC once via esp_adc_cal
  int  readPercent();  // averages BAT_SAMPLE_COUNT analogRead() samples,
                       // doubles for the divider, clamps/maps to 0-100
};
```

No `readMilliVolts()` or other public surface beyond this — nothing else in
the codebase needs the raw voltage, so there's nothing to expose (YAGNI). No
base class or interface — there is exactly one battery on one board.

## Renderer changes

One new private method draws the entire indicator (icon + percent text) and
is called identically from all six existing draw paths — it needs no
per-screen or per-orientation variant because it positions itself purely from
`_tft.width()`, the same trick `drawWifiIndicator` already uses to work
unmodified across rotations:

```cpp
void drawBatteryIcon(int pct); // private
```

**Geometry** (all relative to `_tft.width()`, so identical in every
rotation):

| Element | Position | Notes |
|---|---|---|
| Clear rect (drawn first) | `x=width()-72, y=2, w=50, h=12`, fill `TFT_BLACK` | Erases the previous frame's text/icon in one step before redrawing, so a shrinking percentage ("100%"→"9%") never leaves a stray digit. `TFT_BLACK` is used even on the Settings screen (whose actual background is `colorScreenBg()`, `rgb(8,8,10)`) — the two are visually indistinguishable at this darkness, so `drawBatteryIcon` stays screen-agnostic rather than taking a background-color parameter for an imperceptible difference. |
| Percent text | `setTextFont(1)`, `setTextColor(color)`, `MR_DATUM` at `(width()-45, 8)` | Right-aligned so it always butts up against the icon regardless of digit count. Font, color, and datum are explicit on every call (not inherited from whatever the previous drawing statement left set) — same discipline the rest of `Renderer.cpp` already follows around every temporary `setFreeFont`/`setTextDatum` use (e.g. `drawClaude`'s `setTextDatum(MC_DATUM)` / `setTextDatum(TL_DATUM)` pair). Resets to `setTextFont(0)` / `setTextDatum(TL_DATUM)` before returning so it never leaves state for whichever draw call runs next. |
| Battery body | `drawProgressBar(width()-42, 4, 16, 8, pct, color)` | Reuses the existing progress-bar helper as-is (border + proportional fill) instead of writing new border/fill logic — it already does exactly what a battery body needs. |
| Nub | `fillRect(width()-26, 6, 2, 4, color)` | The one bit of new drawing code needed; `drawProgressBar` has no concept of a battery nub. |

`color` is `TFT_GREEN` when `pct > BAT_LOW_PCT`, else `colorDestructive()` —
a plain inline ternary, not a new named color-mapping helper (the existing
`progressColor()` helper's high-is-bad semantics are inverted from battery's
high-is-good meaning, so it can't be reused directly, and one ternary isn't
worth abstracting).

This block sits at `x ≈ width()-72..width()-24`, `y=2..14` — clear of the
WiFi dot (`width()-10, r=4`, occupying `width()-14..width()-6`) with a 10px
gap, and clear of every screen's existing header content (title text, the
Settings header icon buttons, and the Claude-screen sprite, whose patrol is
capped at `headerWidth/4` — far left of this corner) in both landscape
orientations and in portrait Claude/Grok.

**Unverified risk — portrait Settings only:** `drawSettingsPortrait` centers
`"SETTINGS"` at `x=178`, explicitly chosen (per its own comment) as the
midpoint of the *entire* free zone from the header icons (ending `x=114`) to
the screen edge (`x=240`) — i.e. it was laid out assuming it may use close
to the full available width up to 240. Static analysis can't confirm the
actual rendered glyph width of that `FreeSans9pt7b` string, so overlap with
this design's icon zone (starting at `x=168`) can't be ruled out without
running it on hardware. **This must be checked during implementation/testing**;
if it overlaps, the fix is narrowing the title's centering zone (e.g. center
within `114..168` instead of `114..240`), a one-line coordinate change in
`drawSettingsPortrait`, not a rework of this design.

**New state:** `int _batteryPct = 100;` member (mirrors `_prev` as
Renderer-owned display state, not `AppState` — nothing outside Renderer needs
this value, same reasoning as why `_prev` isn't in `AppState` either).

**New public method:**

```cpp
void setBattery(int pct); // _batteryPct = pct; drawBatteryIcon(_batteryPct);
```

Called from `main.cpp` whenever a fresh reading is taken. Each of the six
existing draw functions (`drawClaude`/`drawGrok`/`drawSettings` ×
landscape/portrait) gets one added line, `drawBatteryIcon(_batteryPct);`,
right after their `fillScreen()` — using the cached value directly, not
calling `setBattery` again (that would just be a redundant store of the same
value it already holds).

No `updateBattery()` wrapper is needed alongside `setBattery()` — unlike
`updateBrightnessBar`/`updateLedToggle` (which exist because their "draw"
and "update" cases touch different amounts of surrounding UI),
`drawBatteryIcon` is already the minimal, self-contained redraw in both the
full-screen-redraw case and the periodic-tick case. Adding a second method
that does the same thing under a different name would be duplication, not
API clarity.

## `main.cpp` integration

- `#include "Battery.h"`, `Battery battery;` alongside the other global
  objects.
- In `setup()`, right after `renderer.showConnecting()`:
  ```cpp
  battery.init();
  renderer.setBattery(battery.readPercent());
  ```
- In `loop()`, inside the existing fetch-interval block (so the reading
  refreshes on the same cadence as the data fetch, independent of whether
  that fetch itself succeeds):
  ```cpp
  if (millis() - lastFetch > state.fetchInterval) {
    renderer.setBattery(battery.readPercent());
    if (fetcher.fetch(data)) {
      ...
  ```

No new `Event`, no new `AppState` field, no new timer variable — it rides
the fetch-interval timer that already exists.

## Files changed

- `src/Config.h` — battery ADC pin + mV/percent constants.
- `src/Battery.h`, `src/Battery.cpp` — new module.
- `src/Renderer.h` — add `_batteryPct` member, `drawBatteryIcon` (private),
  `setBattery` (public).
- `src/Renderer.cpp` — `drawBatteryIcon` implementation; one added call in
  each of the six draw functions.
- `src/main.cpp` — instantiate `Battery`, `init()` + initial `setBattery()`
  call in `setup()`, refresh call in `loop()`'s fetch-interval block.

No changes to `Types.h`, `TouchRouter.*`, `DataFetcher.*`, `AnimatedSprite.*`,
`SpriteData.h`, or `NvsConfig.*` — the battery level is not persisted and has
no touch interaction.

## Testing

No automated test harness exists for `Renderer` or ADC/hardware behavior
(consistent with the rest of this project). Verification is `pio run`
compiling cleanly, then hardware flash + manual checks with the battery
physically connected:

- Battery icon renders in the top-right corner on all three screens, in both
  landscape and portrait, without colliding with the WiFi dot, titles, sprite,
  or Settings header icons — **specifically check portrait Settings**, the
  one placement this design couldn't verify statically (see the flagged risk
  above); narrow the title's centering zone in `drawSettingsPortrait` if it
  overlaps.
- Percentage number and fill level are plausible against a multimeter
  reading of the battery voltage (allowing for the linear approximation).
- Unplugging USB (battery-only power) and replugging it doesn't change the
  displayed percentage in a discontinuous/wrong way (voltage-divider node is
  the same either way).
- Icon turns red at/below `BAT_LOW_PCT` (15%) — verified either on a
  genuinely low pack or by temporarily lowering the threshold for the test.
- A shrinking percentage (e.g. "100%" → "9%" across a reading) leaves no
  stray leftover digit from the previous frame.

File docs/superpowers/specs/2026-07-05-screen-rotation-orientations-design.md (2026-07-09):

# Screen Rotation & Orientation Support

**Date:** 2026-07-05
**Branch:** `esp32-32e-cyd`
**Status:** Approved design

## Goal

Let the user change the display orientation from the Settings screen and support
all four TFT_eSPI rotations (0, 1, 2, 3) — both landscape orientations and both
portrait orientations — with correct touch mapping in each. The chosen orientation
survives reboot.

## Background

The board is physically 240×320. Today the firmware pins rotation to `3`
(landscape, 320×240) in `Renderer::init()` and every screen's drawing code, every
partial-update path, and every `TouchRouter` hit zone is hardcoded for that single
320×240 geometry. Touch calibration `{433, 3490, 314, 3448, 5}` was obtained via
`calibrateTouch()` for rotation 3 specifically.

There are only **two geometries** to support:

| Rotation | Orientation | Canvas (w×h) |
|---|---|---|
| 1, 3 | Landscape | 320 × 240 |
| 0, 2 | Portrait  | 240 × 320 |

## Non-goals

- No Layout-struct refactor. We keep the existing procedural, coordinate-hardcoded
  style and add portrait coordinates via inline `if (portrait)` branches. (Considered
  a shared `Layout` source of truth to also kill the existing Renderer/TouchRouter
  coordinate duplication; rejected to keep this change smaller and land faster. The
  cost we accept: each draw/update function and each touch zone carries its own
  portrait coordinates, and full-draw vs. partial-update pixel-consistency is
  maintained by hand per function.)
- No multi-board build. This stays a hardware-swap branch.

## Design

### 1. Orientation state & persistence

- Add `uint8_t rotation = 3;` to `AppState` in `Types.h` (raw TFT_eSPI rotation 0–3).
- Persist to NVS. Reuse the existing `netcfg` namespace (already used for `proxyIp`),
  new key `rot` (a `uint8_t`).
- Boot order in `setup()`: read `rot` from NVS **before** `renderer.init(...)` so the
  first draw is already in the saved orientation. If no value is stored, default to `3`.
- Runtime change sequence (no reboot):
  1. `state.rotation = next;`
  2. `renderer.setRotation(next)` — calls `_tft.setRotation(next)` then applies that
     rotation's touch calData (see §3).
  3. full redraw of the current screen via `renderer.switchTo(...)`.
  4. save `rot` to NVS.

### 2. Geometry-aware drawing (inline branches)

Introduce a single notion of "is this rotation portrait":
`bool portrait = (rotation == 0 || rotation == 2);`

`Renderer` needs to know the current rotation to branch. Store it as a member
(`uint8_t _rotation`) set by `setRotation()`. A small helper `bool portrait() const`
keeps branches readable.

Every screen gets a portrait coordinate set alongside its existing landscape one:

- `drawClaude` / `updateClaude`
- `drawGrok` / `updateGrok`
- `drawSettings` (+ `drawIntervalButtons`, `updateBrightnessBar`, `drawRebootIcon`,
  `drawLedToggle`, new rotate icon)
- `drawWifiIndicator` (top-right dot position differs per geometry)
- Status screens (`showConnecting`, etc.) — center text using `_tft.width()/height()`
  instead of hardcoded offsets so they work in both geometries with one code path.

**Portrait layout intent (240 wide × 320 tall):**

- *Claude:* header (sprite + "Usage") across the top; HLine; Session block (%, "Session"
  pill, progress bar ~220 wide, reset text); HLine; Weekly block; nav buttons pinned to
  the bottom. Extra vertical room vs. landscape, so blocks get more breathing space;
  progress bars shrink from 300→~220 wide.
- *Grok:* same vertical-stack treatment; bars ~220 wide.
- *Settings:* title row with reboot / LED / rotate icons; Brightness card (~228 wide);
  Refresh card; nav buttons at the bottom. The brightness bar and interval buttons
  shrink to fit 240 width.

Partial-update paths (`updateClaude`, `updateGrok`, `updateBrightnessBar`,
`updateIntervalButtons`, `updateLedToggle`, `updateRebootIcon`) must clear/redraw at
the **same** coordinates their full-draw counterpart used for the current geometry.
Per the board's no-double-buffer quirk, keep clearing to the exact changed region only.

### 3. Touch calibration — derive + on-device recal

**Derive all four in code.** The XPT2046 raw ADC bounds are physically fixed; only the
rotate/invert flags and the axis roles change per rotation. From the rotation-3 baseline
`{433, 3490, 314, 3448, 5}` (flag 5 = rotate=1, invert_x=0, invert_y=1) we know:

- The rotate=true branch maps raw_y → screenX, raw_x → screenY.
- Raw Y range ≈ [433, 3923] (x0=433, span=3490).
- Raw X range ≈ [314, 3762] (y0=314, span=3448).

Construct calData per rotation:

- **Landscape (1, 3):** `rotate = 1`, width/height = 320/240. calData x-part uses the
  raw_y range, y-part uses the raw_x range: `{433, 3490, 314, 3448, flag}`.
- **Portrait (0, 2):** `rotate = 0`, width/height = 240/320. Axis roles swap:
  `{314, 3448, 433, 3490, flag}`.
- **invert bits per rotation:** rotation 3 is the known-good `{invert_x=0, invert_y=1}`.
  The 180° partner (rotation 1) flips both inverts. Portrait rotations 0 and 2 are a
  90° turn (rotate=0) and likewise differ by both inverts. Exact per-rotation invert
  bits are derived in code and **verified on hardware** — if a rotation reads mirrored,
  the recal gesture (below) corrects it permanently without a re-flash.

**NVS override.** Per-rotation calData may be stored in NVS (`netcfg` keys `cal0`…`cal3`,
each a 10-byte blob = 5×uint16_t). `renderer.setRotation(r)` applies the stored blob if
present, otherwise the derived default.

**Recal gesture.** A hidden long-press (~800 ms) on the Settings rotate icon runs
`_tft.calibrateTouch(buf, ...)` for the current rotation, applies the result, and saves
it to `cal{r}`. This is the escape hatch if a derived default is off.

Encapsulate calData construction/lookup in a small helper so `main.cpp` and `Renderer`
share one implementation. NVS access can live next to the existing proxy-cache NVS code
(in `DataFetcher`) or a tiny dedicated helper — implementer's choice, kept in one place.

### 4. Settings UI control

- Add a **rotate icon** to the Settings header, matching the existing reboot/LED icon
  button pattern (`drawRotateIcon(...)`), placed after the LED icon. Portrait Settings
  places the same three icons within the 240-wide header.
- **Short tap** → cycle rotation `3 → 0 → 1 → 2 → 3`, redraw immediately, persist.
- **Long-press (~800 ms)** → recal gesture (§3). The press-and-hold timing is tracked
  in `loop()` similarly to the existing reboot confirm-tap arming, not with a blocking
  delay.
- New events in `Types.h`: `Event::CycleRotation`, `Event::Recalibrate`.
- `TouchRouter` gains a hit zone for the rotate icon (landscape and portrait
  coordinates) and reports the tap; short-vs-long discrimination is handled in `loop()`
  using press-duration, consistent with how reboot arming works today.

### 5. AnimatedSprite

The header mascot patrols within the header on the Claude screen. Its patrol bounds and
draw origin are geometry-dependent (header is 320 wide in landscape, 240 in portrait).
Pass the current width (or a portrait flag) into the sprite so its patrol range and clear
region stay within the header in both geometries.

### 6. Event handling in `loop()`

- `Event::CycleRotation`: compute next rotation, call `renderer.setRotation`, full
  redraw of current screen, persist `rot`.
- `Event::Recalibrate`: call into renderer to run `calibrateTouch` for the current
  rotation, persist the blob, redraw.
- Reset any transient arming state (like reboot's `rebootArmedAt`) when leaving Settings,
  mirroring existing behavior.

## Files touched

- `src/Types.h` — `rotation` field; `CycleRotation`, `Recalibrate` events.
- `src/main.cpp` — load/save `rot` in NVS; boot rotation; handle new events; long-press
  timing.
- `src/Renderer.h/.cpp` — `_rotation` member, `portrait()` helper, `setRotation()`,
  portrait branches in all draw/update paths, rotate icon, geometry-safe status screens,
  calData derivation + NVS override, recal entry point.
- `src/TouchRouter.cpp` — portrait touch zones for every screen; rotate-icon zone.
- `src/AnimatedSprite.h/.cpp` — geometry-aware patrol bounds / clear region.
- `src/DataFetcher.*` (or a small NVS helper) — `rot` and `cal{0..3}` NVS keys.
- `CLAUDE.md` — document the new rotation feature, per-rotation calibration approach,
  and the recal gesture, replacing the "rotation 3 only" framing.

## Testing / verification

This is embedded hardware with no automated test harness, so verification is on-device:

- Boot in each of the 4 rotations (persisted) and confirm each screen renders upright
  and un-clipped in both geometries.
- Confirm touch hits the correct control in every rotation (nav, brightness ±, interval
  buttons, reboot, LED, rotate icon). If any rotation reads mirrored, exercise the recal
  gesture and confirm it persists across reboot.
- Confirm cycling rotation redraws without reboot and the choice survives a power cycle.
- Confirm the mascot patrols within the header (no clipping/tearing) in both geometries.

## Risks

- **Derived invert bits may be wrong for some rotations.** Mitigated by the on-device
  recal gesture + NVS override. Acceptable per the chosen approach.
- **Full-draw / partial-update coordinate drift** between geometries (inline-branch cost).
  Mitigated by keeping each function's landscape and portrait coordinates adjacent and
  reviewing them together.
- **Touch mapping is the historically painful area** on this board (per CLAUDE.md);
  budget on-device iteration for it.

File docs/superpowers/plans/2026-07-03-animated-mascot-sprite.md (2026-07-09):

# Animated Mascot Sprite Implementation Plan

> **For agentic workers:** REQUIRED SUB-SKILL: Use superpowers:subagent-driven-development (recommended) or superpowers:executing-plans to implement this plan task-by-task. Steps use checkbox (`- [ ]`) syntax for tracking.

**Goal:** Replace the static header sprite on the Claude screen with a library of 4 pixel-art characters, one randomly selected and animated at a time, re-rolled every 5 minutes — two of which (Ghost, Robot) patrol back and forth across the header.

**Architecture:** A new `AnimatedSprite` class owns all animation state (character choice, frame index, patrol phase, position) and is driven by a `tick(millis())` call from `loop()`; it redraws only a small fixed "sprite lane" rect in the header, never the full screen. Character pixel data lives in a separate pure-data header (`SpriteData.h`). `Renderer` owns one `AnimatedSprite` instance and exposes `tickSprite()`.

**Tech Stack:** C++/Arduino framework, ESP32 (esp32dev), TFT_eSPI (vendored in `lib/`), PlatformIO. No test framework exists in this repo — verification is `pio run` compilation checks plus a final manual on-device check (per the design spec's Testing section).

## Global Constraints

- Board: ESP32-WROOM-32E, ST7789P3 240×320 rotation 3 — see `CLAUDE.md` for hardware quirks (`USER_SETUP_LOADED=1` must stay set; vendored `lib/TFT_eSPI` must keep being used, not the registry copy).
- Scope: Claude screen only. Grok screen is untouched.
- Shared body/accent color pair for all characters (no per-character colors).
- `esp_random()` for character selection — no seeding needed on ESP32.
- Full spec: `docs/superpowers/specs/2026-07-03-animated-mascot-sprite-design.md`.

---

### Task 1: Sprite data + `AnimatedSprite` class (standalone, not yet wired in)

**Files:**
- Create: `src/SpriteData.h`
- Create: `src/AnimatedSprite.h`
- Create: `src/AnimatedSprite.cpp`

**Interfaces:**
- Produces (consumed by Task 2):
  - `enum class SpriteMotion { STATIC, PATROL_GLIDE, PATROL_HOP };`
  - `struct Character { const SpriteFrame* frames[4]; SpriteMotion motion; };`
  - `static const int NUM_CHARACTERS = 4;`
  - `static const Character CHARACTERS[NUM_CHARACTERS];`
  - `class AnimatedSprite { public: void tick(unsigned long nowMs); bool needsRedraw() const; void draw(TFT_eSPI& tft); ... };`

- [ ] **Step 1: Create `src/SpriteData.h` with the 4 characters' pixel grids**

```cpp
#pragma once
#include <Arduino.h>

// Pixel-art mascot data: 12 rows x 10 cols per frame, 4 frames per character.
// 0=transparent, 1=body, 2=accent — the actual colors are chosen by the
// caller (AnimatedSprite::draw), not stored here.

typedef uint8_t SpriteFrame[12][10];

enum class SpriteMotion { STATIC, PATROL_GLIDE, PATROL_HOP };

struct Character {
  const SpriteFrame* frames[4];
  SpriteMotion        motion;
};

// ── Character 0: Bot — blink + smile-widen idle loop, stays in place ───────
static const SpriteFrame BOT_F0 PROGMEM = {
  {0,1,0,0,0,0,0,0,1,0},
  {0,0,0,0,0,0,0,0,0,0},
  {0,0,1,1,1,1,1,1,0,0},
  {0,1,1,1,1,1,1,1,1,0},
  {1,1,2,1,1,1,1,2,1,1},
  {1,1,1,1,1,1,1,1,1,1},
  {0,1,2,1,1,1,1,2,1,0},
  {0,0,1,1,1,1,1,1,0,0},
  {0,1,1,1,1,1,1,1,1,0},
  {1,1,1,1,1,1,1,1,1,1},
  {0,0,1,1,0,0,1,1,0,0},
  {0,0,1,1,0,0,1,1,0,0},
};
static const SpriteFrame BOT_F1 PROGMEM = { // blink
  {0,1,0,0,0,0,0,0,1,0},
  {0,0,0,0,0,0,0,0,0,0},
  {0,0,1,1,1,1,1,1,0,0},
  {0,1,1,1,1,1,1,1,1,0},
  {1,1,1,1,1,1,1,1,1,1},
  {1,1,1,1,1,1,1,1,1,1},
  {0,1,2,1,1,1,1,2,1,0},
  {0,0,1,1,1,1,1,1,0,0},
  {0,1,1,1,1,1,1,1,1,0},
  {1,1,1,1,1,1,1,1,1,1},
  {0,0,1,1,0,0,1,1,0,0},
  {0,0,1,1,0,0,1,1,0,0},
};
static const SpriteFrame BOT_F2 PROGMEM = { // wide smile
  {0,1,0,0,0,0,0,0,1,0},
  {0,0,0,0,0,0,0,0,0,0},
  {0,0,1,1,1,1,1,1,0,0},
  {0,1,1,1,1,1,1,1,1,0},
  {1,1,2,1,1,1,1,2,1,1},
  {1,1,1,1,1,1,1,1,1,1},
  {0,1,2,2,1,1,2,2,1,0},
  {0,0,1,1,1,1,1,1,0,0},
  {0,1,1,1,1,1,1,1,1,0},
  {1,1,1,1,1,1,1,1,1,1},
  {0,0,1,1,0,0,1,1,0,0},
  {0,0,1,1,0,0,1,1,0,0},
};

// ── Character 1: Ghost — floaty, wavy tail, patrols with a smooth glide ────
static const SpriteFrame GHOST_F0 PROGMEM = { // tail wave A
  {0,0,0,1,1,1,1,0,0,0},
  {0,0,1,1,1,1,1,1,0,0},
  {0,1,1,1,1,1,1,1,1,0},
  {1,1,1,1,1,1,1,1,1,1},
  {1,1,2,1,1,1,1,2,1,1},
  {1,1,1,1,1,1,1,1,1,1},
  {1,1,1,1,1,1,1,1,1,1},
  {1,1,1,1,1,1,1,1,1,1},
  {1,1,1,1,1,1,1,1,1,1},
  {1,1,1,1,1,1,1,1,1,1},
  {1,0,1,1,0,1,1,0,1,1},
  {0,0,0,0,0,0,0,0,0,0},
};
static const SpriteFrame GHOST_F1 PROGMEM = { // tail wave B
  {0,0,0,1,1,1,1,0,0,0},
  {0,0,1,1,1,1,1,1,0,0},
  {0,1,1,1,1,1,1,1,1,0},
  {1,1,1,1,1,1,1,1,1,1},
  {1,1,2,1,1,1,1,2,1,1},
  {1,1,1,1,1,1,1,1,1,1},
  {1,1,1,1,1,1,1,1,1,1},
  {1,1,1,1,1,1,1,1,1,1},
  {1,1,1,1,1,1,1,1,1,1},
  {1,1,1,1,1,1,1,1,1,1},
  {0,1,1,0,1,1,0,1,1,0},
  {0,0,0,0,0,0,0,0,0,0},
};

// ── Character 2: Cat — pointy ears, blinking, stays in place ───────────────
static const SpriteFrame CAT_F_OPEN PROGMEM = {
  {1,0,0,0,0,0,0,0,0,1},
  {1,1,0,0,0,0,0,0,1,1},
  {0,1,1,1,1,1,1,1,1,0},
  {0,1,1,1,1,1,1,1,1,0},
  {1,1,2,1,1,1,2,1,1,1},
  {1,1,1,1,1,1,1,1,1,1},
  {0,1,1,2,1,1,2,1,1,0},
  {0,0,1,1,1,1,1,1,0,0},
  {0,1,1,1,1,1,1,1,1,0},
  {1,1,1,1,1,1,1,1,1,1},
  {0,0,1,1,0,0,1,1,0,0},
  {0,0,1,1,0,0,1,1,0,0},
};
static const SpriteFrame CAT_F_BLINK PROGMEM = {
  {1,0,0,0,0,0,0,0,0,1},
  {1,1,0,0,0,0,0,0,1,1},
  {0,1,1,1,1,1,1,1,1,0},
  {0,1,1,1,1,1,1,1,1,0},
  {1,1,1,1,1,1,1,1,1,1},
  {1,1,1,1,1,1,1,1,1,1},
  {0,1,1,2,1,1,2,1,1,0},
  {0,0,1,1,1,1,1,1,0,0},
  {0,1,1,1,1,1,1,1,1,0},
  {1,1,1,1,1,1,1,1,1,1},
  {0,0,1,1,0,0,1,1,0,0},
  {0,0,1,1,0,0,1,1,0,0},
};

// ── Character 3: Robot — single eye band scans left/right, patrols by hop ──
static const SpriteFrame ROBOT_F_CENTER PROGMEM = {
  {0,0,1,1,1,1,1,1,0,0},
  {1,1,1,1,1,1,1,1,1,1},
  {1,1,1,1,1,1,1,1,1,1},
  {1,1,1,2,2,2,2,1,1,1},
  {1,1,1,2,2,2,2,1,1,1},
  {1,1,1,1,1,1,1,1,1,1},
  {0,1,1,1,1,1,1,1,1,0},
  {0,0,1,1,1,1,1,1,0,0},
  {0,1,1,1,1,1,1,1,1,0},
  {1,1,1,1,1,1,1,1,1,1},
  {0,0,1,1,0,0,1,1,0,0},
  {0,0,1,1,0,0,1,1,0,0},
};
static const SpriteFrame ROBOT_F_LEFT PROGMEM = {
  {0,0,1,1,1,1,1,1,0,0},
  {1,1,1,1,1,1,1,1,1,1},
  {1,1,1,1,1,1,1,1,1,1},
  {1,2,2,2,2,1,1,1,1,1},
  {1,2,2,2,2,1,1,1,1,1},
  {1,1,1,1,1,1,1,1,1,1},
  {0,1,1,1,1,1,1,1,1,0},
  {0,0,1,1,1,1,1,1,0,0},
  {0,1,1,1,1,1,1,1,1,0},
  {1,1,1,1,1,1,1,1,1,1},
  {0,0,1,1,0,0,1,1,0,0},
  {0,0,1,1,0,0,1,1,0,0},
};
static const SpriteFrame ROBOT_F_RIGHT PROGMEM = {
  {0,0,1,1,1,1,1,1,0,0},
  {1,1,1,1,1,1,1,1,1,1},
  {1,1,1,1,1,1,1,1,1,1},
  {1,1,1,1,1,2,2,2,2,1},
  {1,1,1,1,1,2,2,2,2,1},
  {1,1,1,1,1,1,1,1,1,1},
  {0,1,1,1,1,1,1,1,1,0},
  {0,0,1,1,1,1,1,1,0,0},
  {0,1,1,1,1,1,1,1,1,0},
  {1,1,1,1,1,1,1,1,1,1},
  {0,0,1,1,0,0,1,1,0,0},
  {0,0,1,1,0,0,1,1,0,0},
};

static const int NUM_CHARACTERS = 4;
static const Character CHARACTERS[NUM_CHARACTERS] = {
  { {&BOT_F0, &BOT_F1, &BOT_F2, &BOT_F0}, SpriteMotion::STATIC },
  { {&GHOST_F0, &GHOST_F1, &GHOST_F0, &GHOST_F1}, SpriteMotion::PATROL_GLIDE },
  { {&CAT_F_OPEN, &CAT_F_OPEN, &CAT_F_BLINK, &CAT_F_OPEN}, SpriteMotion::STATIC },
  { {&ROBOT_F_CENTER, &ROBOT_F_LEFT, &ROBOT_F_CENTER, &ROBOT_F_RIGHT}, SpriteMotion::PATROL_HOP },
};
```

- [ ] **Step 2: Create `src/AnimatedSprite.h`**

```cpp
#pragma once
#include <Arduino.h>
#include <TFT_eSPI.h>
#include "SpriteData.h"

class AnimatedSprite {
public:
  void tick(unsigned long nowMs);
  bool needsRedraw() const { return _redrawNeeded; }
  void draw(TFT_eSPI& tft);

private:
  enum class Phase { Idle, Entering, AtLeft, ToTitle, AtTitle, ToLeft };

  bool          _initialized  = false;
  int           _character    = 0;
  int           _frame        = 0;
  unsigned long _lastFrameMs  = 0;
  unsigned long _lastRerollMs = 0;
  unsigned long _lastTickMs   = 0;
  Phase         _phase        = Phase::Idle;
  unsigned long _phaseStartMs = 0;
  float         _x            = 5.0f;
  bool          _redrawNeeded = false;

  void reroll(unsigned long nowMs);
};
```

- [ ] **Step 3: Create `src/AnimatedSprite.cpp`**

```cpp
#include "AnimatedSprite.h"
#include <esp_random.h>
#include <cmath>

namespace {
  constexpr int   LANE_W  = 140;
  constexpr int   LANE_H  = 44;
  constexpr int   SPRITE_Y = 2;
  constexpr float START_X = -33.0f;
  constexpr float REST_X  = 5.0f;
  constexpr float TITLE_X = 95.0f; // TODO: tune on hardware to clear the "Usage" title's left edge

  constexpr unsigned long ENTER_DUR_MS       = 5000;
  constexpr unsigned long PAUSE_MS           = 2000;
  constexpr unsigned long LEG_DUR_MS         = 3000;
  constexpr unsigned long FRAME_INTERVAL_MS  = 250;
  constexpr unsigned long REROLL_INTERVAL_MS = 300000UL;
  constexpr unsigned long MIN_TICK_MS        = 80;

  constexpr int HOP_STEP_PX   = 6;
  constexpr int HOP_BOUNCE_PX = 3;
  constexpr int NUM_FRAMES    = 4;

  float easeInOutQuad(float t) {
    return t < 0.5f ? 2.0f * t * t : -1.0f + (4.0f - 2.0f * t) * t;
  }
}

void AnimatedSprite::reroll(unsigned long nowMs) {
  _character    = esp_random() % NUM_CHARACTERS;
  _frame        = 0;
  _lastFrameMs  = nowMs;
  _lastRerollMs = nowMs;
  if (CHARACTERS[_character].motion == SpriteMotion::STATIC) {
    _phase = Phase::Idle;
    _x     = REST_X;
  } else {
    _phase        = Phase::Entering;
    _phaseStartMs = nowMs;
    _x            = START_X;
  }
}

void AnimatedSprite::tick(unsigned long nowMs) {
  _redrawNeeded = false;

  if (!_initialized) {
    _initialized = true;
    reroll(nowMs);
    _lastTickMs   = nowMs;
    _redrawNeeded = true;
    return;
  }

  if (nowMs - _lastRerollMs >= REROLL_INTERVAL_MS) {
    reroll(nowMs);
    _redrawNeeded = true;
  }

  if (nowMs - _lastTickMs < MIN_TICK_MS) return;
  _lastTickMs = nowMs;

  if (nowMs - _lastFrameMs >= FRAME_INTERVAL_MS) {
    _frame       = (_frame + 1) % NUM_FRAMES;
    _lastFrameMs = nowMs;
    _redrawNeeded = true;
  }

  float newX = _x;
  switch (_phase) {
    case Phase::Idle:
      newX = REST_X;
      break;
    case Phase::Entering: {
      float p = float(nowMs - _phaseStartMs) / ENTER_DUR_MS;
      if (p >= 1.0f) {
        newX = REST_X;
        _phase = Phase::AtLeft;
        _phaseStartMs = nowMs;
      } else {
        newX = START_X + (REST_X - START_X) * easeInOutQuad(p);
      }
      break;
    }
    case Phase::AtLeft:
      newX = REST_X;
      if (nowMs - _phaseStartMs >= PAUSE_MS) {
        _phase = Phase::ToTitle;
        _phaseStartMs = nowMs;
      }
      break;
    case Phase::ToTitle: {
      float p = float(nowMs - _phaseStartMs) / LEG_DUR_MS;
      if (p >= 1.0f) {
        newX = TITLE_X;
        _phase = Phase::AtTitle;
        _phaseStartMs = nowMs;
      } else {
        newX = REST_X + (TITLE_X - REST_X) * easeInOutQuad(p);
      }
      break;
    }
    case Phase::AtTitle:
      newX = TITLE_X;
      if (nowMs - _phaseStartMs >= PAUSE_MS) {
        _phase = Phase::ToLeft;
        _phaseStartMs = nowMs;
      }
      break;
    case Phase::ToLeft: {
      float p = float(nowMs - _phaseStartMs) / LEG_DUR_MS;
      if (p >= 1.0f) {
        newX = REST_X;
        _phase = Phase::AtLeft;
        _phaseStartMs = nowMs;
      } else {
        newX = TITLE_X + (REST_X - TITLE_X) * easeInOutQuad(p);
      }
      break;
    }
  }

  if (newX != _x) {
    _x = newX;
    _redrawNeeded = true;
  }
}

void AnimatedSprite::draw(TFT_eSPI& tft) {
  tft.fillRect(0, 0, LANE_W, LANE_H, TFT_BLACK);

  const uint16_t body = tft.color565(210, 90, 42);
  const uint16_t dark = tft.color565(130, 50, 15);

  const Character&    ch    = CHARACTERS[_character];
  const SpriteFrame&   frame = *ch.frames[_frame];

  int drawX = (int)_x;
  int drawY = SPRITE_Y;

  if (ch.motion == SpriteMotion::PATROL_HOP) {
    long step = lroundf(drawX / (float)HOP_STEP_PX);
    drawX = (int)(step * HOP_STEP_PX);
    drawY = SPRITE_Y - ((step % 2 == 0) ? 0 : HOP_BOUNCE_PX);
  }

  for (int r = 0; r < 12; r++) {
    for (int c = 0; c < 10; c++) {
      uint8_t v = pgm_read_byte(&frame[r][c]);
      if (v) tft.fillRect(drawX + c * 3, drawY + r * 3, 3, 3, v == 1 ? body : dark);
    }
  }

  _redrawNeeded = false;
}
```

- [ ] **Step 4: Compile check**

Run: `pio run`
Expected: `SUCCESS` (this compiles `AnimatedSprite.cpp` as its own translation unit even though nothing references the class yet — PlatformIO compiles every `.cpp` under `src/`).

- [ ] **Step 5: Commit**

```bash
git add src/SpriteData.h src/AnimatedSprite.h src/AnimatedSprite.cpp
git commit -m "Add AnimatedSprite class and mascot pixel-art data

Not yet wired into Renderer — standalone, compile-checked only."
```

---

### Task 2: Wire `AnimatedSprite` into `Renderer`, remove the old static sprite

**Files:**
- Modify: `src/Renderer.h`
- Modify: `src/Renderer.cpp:21-36` (delete old `SPR` array), `src/Renderer.cpp:117-124` (replace inline blit)

**Interfaces:**
- Consumes: `AnimatedSprite` from Task 1 (`tick()`, `needsRedraw()`, `draw()`).
- Produces (consumed by Task 3): `void Renderer::tickSprite();`

- [ ] **Step 1: Add the `AnimatedSprite` member and `tickSprite()` declaration to `src/Renderer.h`**

In `src/Renderer.h`, add the include and member/method:

```cpp
#pragma once
#include <TFT_eSPI.h>
#include "Types.h"
#include "AnimatedSprite.h"

class Renderer {
  TFT_eSPI      _tft;
  UsageData     _prev = { -1, -1, -1, -1, -1 };
  AnimatedSprite _sprite;
```

And add `void tickSprite();` to the public section, alongside the other `void` methods (e.g. right after `void drawWifiIndicator(bool on);`).

- [ ] **Step 2: Delete the old `SPR` array from `src/Renderer.cpp`**

Remove these lines (currently `src/Renderer.cpp:21-36`):

```cpp
// Pixel-art sprite: 10 cols × 12 rows, each cell = 3×3 px → 30×36 px total
// 0=transparent, 1=body, 2=accent
static const uint8_t SPR[12][10] PROGMEM = {
  {0,1,0,0,0,0,0,0,1,0},   // antennae
  {0,0,0,0,0,0,0,0,0,0},
  {0,0,1,1,1,1,1,1,0,0},   // head
  {0,1,1,1,1,1,1,1,1,0},
  {1,1,2,1,1,1,1,2,1,1},   // eyes
  {1,1,1,1,1,1,1,1,1,1},
  {0,1,2,1,1,1,1,2,1,0},   // smile
  {0,0,1,1,1,1,1,1,0,0},
  {0,1,1,1,1,1,1,1,1,0},   // body
  {1,1,1,1,1,1,1,1,1,1},
  {0,0,1,1,0,0,1,1,0,0},   // legs
  {0,0,1,1,0,0,1,1,0,0},
};
```

- [ ] **Step 3: Replace the inline blit loop in `drawClaude()` with `_sprite.draw(_tft)`**

In `drawClaude()` (currently `src/Renderer.cpp:117-124`), replace:

```cpp
  // ── Header: sprite + title ─────────────────────────────────────────────────
  const uint16_t body = _tft.color565(210, 90, 42);
  const uint16_t dark = _tft.color565(130, 50, 15);
  for (int r = 0; r < 12; r++)
    for (int c = 0; c < 10; c++) {
      uint8_t v = pgm_read_byte(&SPR[r][c]);
      if (v) _tft.fillRect(5 + c * 3, 2 + r * 3, 3, 3, v == 1 ? body : dark);
    }
```

with:

```cpp
  // ── Header: sprite + title ─────────────────────────────────────────────────
  _sprite.draw(_tft);
```

- [ ] **Step 4: Add `Renderer::tickSprite()` at the end of `src/Renderer.cpp`**

```cpp
void Renderer::tickSprite() {
  _sprite.tick(millis());
  if (_sprite.needsRedraw()) _sprite.draw(_tft);
}
```

- [ ] **Step 5: Compile check**

Run: `pio run`
Expected: `SUCCESS`

- [ ] **Step 6: Commit**

```bash
git add src/Renderer.h src/Renderer.cpp
git commit -m "Wire AnimatedSprite into Renderer, remove static header sprite"
```

---

### Task 3: Drive the sprite tick from `loop()`

**Files:**
- Modify: `src/main.cpp:55-100` (inside `loop()`)

**Interfaces:**
- Consumes: `Renderer::tickSprite()` from Task 2.

- [ ] **Step 1: Call `renderer.tickSprite()` once per loop iteration while on the Claude screen**

In `src/main.cpp`, at the top of `loop()` (right after the opening brace, before the `touch.poll()` switch, so it runs every iteration regardless of touch/fetch events):

```cpp
void loop() {
  if (state.screen == 0) renderer.tickSprite();

  switch (touch.poll(state.screen)) {
```

- [ ] **Step 2: Compile check**

Run: `pio run`
Expected: `SUCCESS`

- [ ] **Step 3: Commit**

```bash
git add src/main.cpp
git commit -m "Drive AnimatedSprite tick from the main loop on the Claude screen"
```

---

### Task 4: Flash and verify on hardware

**Files:** none (verification only)

- [ ] **Step 1: Build and upload**

Run: `pio run -t upload`
Expected: upload succeeds, device reboots.

- [ ] **Step 2: Manual verification checklist (per the design spec's Testing section)**

With the device on the Claude screen, over a few minutes confirm:
- A mascot appears in the header and idle-animates (Bot: blinks/smile-widens; Cat: blinks; Ghost/Robot: idle-cycle continues even while paused).
- If Ghost or Robot is showing: it plays a one-time off-screen entrance, then repeatedly paces left-spot → title-spot → left-spot with visible pauses at each end, without ever leaving the screen after the first entrance.
- The sprite never clips or flickers the "Usage" title text. If it does, adjust `TITLE_X` in `AnimatedSprite.cpp` (currently `80.0f`) down until it clears the title's left edge, then re-flash. (`draw()` only ever clears the sprite's own footprint now, not a separate wide lane, so there's no second constant to keep in sync.)
- Every WiFi fetch / screen switch still redraws the rest of the Claude screen correctly (progress bars, percentages) — the sprite change shouldn't have disturbed `drawClaude()`/`updateClaude()`.
- Leave it running ~5+ minutes to confirm the character changes (reroll).

- [ ] **Step 3: If `TITLE_X` needed adjustment, commit the tuned value**

```bash
git add src/AnimatedSprite.cpp
git commit -m "Tune TITLE_X to clear the Usage title on physical hardware"
```

(Skip this step if no adjustment was needed.)

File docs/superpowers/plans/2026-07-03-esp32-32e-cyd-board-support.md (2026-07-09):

# ESP32-32E CYD Board Support Implementation Plan

> **For agentic workers:** REQUIRED SUB-SKILL: Use superpowers:subagent-driven-development (recommended) or superpowers:executing-plans to implement this plan task-by-task. Steps use checkbox (`- [ ]`) syntax for tracking.

**Goal:** Get this firmware building and running on the "3.2 ESP32-32E 240x320 Resistance Touch" all-in-one board (ST7789P3 driver, fixed pinout) on a dedicated `esp32-32e-cyd` branch, replacing the physical status LED (which the new board's pinout can't support) with an on-screen indicator.

**Architecture:** Direct hardware swap — `platformio.ini` and `Config.h` are edited in place for the new board's driver and pins (no dual-env, no `#ifdef`s). `DataFetcher` gains an optional tick callback so it can report WiFi connect/blink state without depending on `Renderer` or touching a GPIO directly; `main.cpp` wires that callback to a new `Renderer::drawWifiIndicator()` method. This preserves the existing three-way separation between `DataFetcher` (WiFi/HTTP only), `Renderer` (pure drawing), and `TouchRouter` (input only) documented in `CLAUDE.md`.

**Tech Stack:** PlatformIO, Arduino framework for ESP32, TFT_eSPI (ST7789 driver), ArduinoJson.

## Global Constraints

- Board: ESP32-32E, ST7789P3 driver, 240×320, TFT pins CS=15 DC=2 RST=EN(no GPIO) MOSI=13 SCLK=14 MISO=12 BL=27; touch (XPT2046) CS=33 IRQ=36 sharing the TFT SPI bus. (From `docs/superpowers/specs/2026-07-03-esp32-32e-cyd-board-support-design.md`.)
- GPIO2 and GPIO14 are unavailable (claimed by TFT DC and SCLK) — do not reuse them for LED/backlight.
- No `#ifdef`/dual-PlatformIO-env support — this branch targets only the new board.
- `DataFetcher` must not `#include` or reference `Renderer`/`TFT_eSPI` — it communicates status only via the callback.
- No physical LED code on this branch — status is shown on-screen via `Renderer::drawWifiIndicator()`.
- Build verification command for every task: `~/.platformio/penv/bin/pio run -e esp32dev` run from the repo root (PlatformIO CLI is not on `PATH` in this environment but is installed there).
- Hardware flashing/on-device verification cannot be performed by the agent (no USB/serial access in this environment) — those steps are explicitly for the user to run.

---

### Task 1: Create branch and swap `platformio.ini` for the new board

**Files:**
- Modify: `platformio.ini`

**Interfaces:**
- Produces: build flags consumed by TFT_eSPI at compile time (`ST7789_DRIVER`, `TFT_CS`, `TFT_DC`, `TFT_RST`, `TFT_MOSI`, `TFT_SCLK`, `TFT_MISO`, `TFT_BL`, `TOUCH_CS`) — later tasks (`Config.h`, `Renderer.cpp`) assume these are set correctly for a 240×320 ST7789P3 panel.

- [ ] **Step 1: Create and switch to the branch**

```bash
git checkout -b esp32-32e-cyd
```

- [ ] **Step 2: Replace the TFT_eSPI build flags in `platformio.ini`**

Replace the entire `build_flags` block (currently lines 19-36) with:

```ini
build_flags =
    -DST7789_DRIVER
    -DTFT_RGB_ORDER=TFT_BGR
    -DTFT_INVERSION_ON
    -DTFT_WIDTH=240
    -DTFT_HEIGHT=320
    -DTFT_CS=15
    -DTFT_DC=2
    -DTFT_RST=-1
    -DTFT_MOSI=13
    -DTFT_SCLK=14
    -DTFT_MISO=12
    -DTFT_BL=27
    -DTFT_BACKLIGHT_ON=HIGH
    -DTOUCH_CS=33
    -DSPI_FREQUENCY=40000000
    -DSPI_TOUCH_FREQUENCY=2500000
    -DLOAD_GLCD
    -DLOAD_FONT2
    -DLOAD_FONT4
    -DSMOOTH_FONT
    -DLOAD_GFXFF
```

`TFT_RST=-1` means "no dedicated reset pin" (this board ties TFT reset to
the ESP32's EN/reset line). `TFT_RGB_ORDER=TFT_BGR` and `TFT_INVERSION_ON`
are the near-universal settings needed for ST7789 panels in TFT_eSPI to
show correct (non color-swapped, non-inverted) colors — Task 6 has the
on-device check to confirm or flip these.

- [ ] **Step 3: Verify it builds**

```bash
~/.platformio/penv/bin/pio run -e esp32dev
```

Expected: `SUCCESS` — this only proves the new flags compile with TFT_eSPI;
it does not prove the display works, since that requires the physical
board (Task 6).

- [ ] **Step 4: Commit**

```bash
git add platformio.ini
git commit -m "Switch build to ST7789P3 driver and ESP32-32E CYD board pinout"
```

---

### Task 2: Update `Config.h` for the new board's pin constraints

**Files:**
- Modify: `src/Config.h`

**Interfaces:**
- Consumes: nothing new.
- Produces: `TFT_BL_PIN` is now 27, matching Task 1's `-DTFT_BL=27`. `LED_PIN` no longer exists — Task 4/5 must not reference it.

- [ ] **Step 1: Edit `Config.h`**

Replace the full contents of `src/Config.h` with:

```cpp
#pragma once

#define TFT_BL_PIN 27
#define BL_CHANNEL 0
#define BL_FREQ    5000
#define BL_RES     8
```

(`LED_PIN` is removed — GPIO2 is the TFT DC line on this board. The status
LED is replaced by an on-screen indicator in Task 3-5.)

- [ ] **Step 2: Verify it builds**

```bash
~/.platformio/penv/bin/pio run -e esp32dev
```

Expected: This will currently **FAIL** with `'LED_PIN' was not declared in
this scope`, because `main.cpp` and `DataFetcher.cpp` still reference it.
That's expected at this point in the plan — confirm the error mentions
`LED_PIN` specifically (not an unrelated failure) before moving on.

- [ ] **Step 3: Commit**

```bash
git add src/Config.h
git commit -m "Drop LED_PIN, move backlight to GPIO27 for ESP32-32E CYD board"
```

---

### Task 3: Add `Renderer::drawWifiIndicator()`

**Files:**
- Modify: `src/Renderer.h`
- Modify: `src/Renderer.cpp`

**Interfaces:**
- Consumes: `TFT_eSPI& _tft` (existing member).
- Produces: `void drawWifiIndicator(bool on)` — public method. Task 5 wires this into a callback passed to `DataFetcher`.

- [ ] **Step 1: Declare the method in `Renderer.h`**

In `src/Renderer.h`, add `void drawWifiIndicator(bool on);` to the public
section, after `updateLedToggle`:

```cpp
  void updateLedToggle(bool ledEnabled);
  void drawWifiIndicator(bool on);
};
```

- [ ] **Step 2: Implement it in `Renderer.cpp`**

Add this at the end of `src/Renderer.cpp`, after `updateIntervalButtons`:

```cpp
void Renderer::drawWifiIndicator(bool on) {
  _tft.fillCircle(310, 8, 4, on ? TFT_GREEN : TFT_BLACK);
}
```

Top-right corner (310, 8) is clear of content on every screen (`Claude`'s
sprite header ends at x≈35, `Grok`'s and `Settings`' titles start at
x=10 and are far short of x=306), and it's overwritten naturally by the
next full-screen redraw (`fillScreen` in `drawClaude`/`drawGrok`/
`drawSettings`), so it never needs explicit clearing elsewhere.

- [ ] **Step 3: Verify it builds**

```bash
~/.platformio/penv/bin/pio run -e esp32dev
```

Expected: Still **FAILS** with the same `LED_PIN` error as Task 2 — this
task only adds a new method, it doesn't yet fix the callers. Confirm no
*new* errors were introduced (e.g. no `Renderer.h`/`.cpp` syntax errors).

- [ ] **Step 4: Commit**

```bash
git add src/Renderer.h src/Renderer.cpp
git commit -m "Add Renderer::drawWifiIndicator for on-screen WiFi status dot"
```

---

### Task 4: Replace direct GPIO blink in `DataFetcher` with a callback

**Files:**
- Modify: `src/DataFetcher.h`
- Modify: `src/DataFetcher.cpp`

**Interfaces:**
- Consumes: nothing new (still only `WiFi`, `HTTPClient`, `ArduinoJson`).
- Produces: `void setIndicatorCallback(void (*callback)(bool))` — public
  method. Task 5's `main.cpp` calls this once at startup with a function
  that forwards to `Renderer::drawWifiIndicator`. The callback receives
  `true` when the indicator should show "on" (blinking-on or
  connected-and-enabled) and `false` otherwise; `DataFetcher` handles the
  `ledEnabled` gating internally before invoking it, so the callback itself
  doesn't need to know about the enabled/disabled setting.

- [ ] **Step 1: Update `DataFetcher.h`**

Replace the full contents of `src/DataFetcher.h` with:

```cpp
#pragma once
#include <Arduino.h>
#include "Types.h"

class DataFetcher {
  const char* _ssid;
  const char* _password;
  const char* _url;
  int _failures = 0;
  bool _ledEnabled = true;
  void (*_indicatorCallback)(bool) = nullptr;

  void ensureWifi();
  void setIndicator(bool on);

public:
  DataFetcher(const char* ssid, const char* password, const char* url);
  bool connect(unsigned long timeoutMs = 15000);
  bool fetch(UsageData& out);
  int  consecutiveFailures() const;
  void setLedEnabled(bool enabled);
  void setIndicatorCallback(void (*callback)(bool));
};
```

- [ ] **Step 2: Update `DataFetcher.cpp`**

Replace `src/DataFetcher.cpp` lines 1-36 (everything from the `#include`s
through the end of `setLedEnabled`) with:

```cpp
#include "DataFetcher.h"
#include "Config.h"
#include <WiFi.h>
#include <HTTPClient.h>
#include <ArduinoJson.h>

DataFetcher::DataFetcher(const char* ssid, const char* password, const char* url)
  : _ssid(ssid), _password(password), _url(url) {}

void DataFetcher::setIndicator(bool on) {
  if (_indicatorCallback) _indicatorCallback(_ledEnabled && on);
}

void DataFetcher::ensureWifi() {
  if (WiFi.status() == WL_CONNECTED) return;
  WiFi.disconnect(false);
  WiFi.begin(_ssid, _password);
  unsigned long t = millis();
  bool blinkOn = false;
  while (WiFi.status() != WL_CONNECTED && millis() - t < 10000) {
    blinkOn = !blinkOn;
    setIndicator(blinkOn);
    delay(250);
  }
  setIndicator(WiFi.status() == WL_CONNECTED);
}

bool DataFetcher::connect(unsigned long timeoutMs) {
  WiFi.begin(_ssid, _password);
  unsigned long t = millis();
  bool blinkOn = false;
  while (WiFi.status() != WL_CONNECTED && millis() - t < timeoutMs) {
    blinkOn = !blinkOn;
    setIndicator(blinkOn);
    delay(250);
  }
  setIndicator(WiFi.status() == WL_CONNECTED);
  return WiFi.status() == WL_CONNECTED;
}

void DataFetcher::setLedEnabled(bool enabled) {
  _ledEnabled = enabled;
  setIndicator(WiFi.status() == WL_CONNECTED);
}

void DataFetcher::setIndicatorCallback(void (*callback)(bool)) {
  _indicatorCallback = callback;
}
```

Leave `fetch()` and `consecutiveFailures()` (the rest of the file)
unchanged.

- [ ] **Step 3: Verify it builds**

```bash
~/.platformio/penv/bin/pio run -e esp32dev
```

Expected: Still **FAILS**, but now only on `main.cpp`'s `pinMode(LED_PIN,
OUTPUT);` — confirm `DataFetcher.cpp` no longer appears in the error
output.

- [ ] **Step 4: Commit**

```bash
git add src/DataFetcher.h src/DataFetcher.cpp
git commit -m "Replace DataFetcher's direct LED GPIO blink with an indicator callback"
```

---

### Task 5: Wire the callback in `main.cpp` and drop the LED pin setup

**Files:**
- Modify: `src/main.cpp`

**Interfaces:**
- Consumes: `Renderer::drawWifiIndicator(bool)` (Task 3),
  `DataFetcher::setIndicatorCallback(void (*)(bool))` (Task 4).
- Produces: nothing further downstream — this is the last task that touches
  compiled code.

- [ ] **Step 1: Remove the LED pin setup and add the indicator wiring**

In `src/main.cpp`, replace:

```cpp
unsigned long lastFetch = 0;

void setup() {
  Serial.begin(115200);
  esp_log_level_set("*", ESP_LOG_NONE);
  pinMode(LED_PIN, OUTPUT);

  renderer.init(state.brightness);
```

with:

```cpp
unsigned long lastFetch = 0;

void wifiIndicator(bool on) {
  renderer.drawWifiIndicator(on);
}

void setup() {
  Serial.begin(115200);
  esp_log_level_set("*", ESP_LOG_NONE);
  fetcher.setIndicatorCallback(wifiIndicator);

  renderer.init(state.brightness);
```

(`wifiIndicator` is a free function, not a lambda, because
`DataFetcher::setIndicatorCallback` takes a plain function pointer with no
captures — it references the global `renderer` the same way the rest of
`main.cpp` already does.)

- [ ] **Step 2: Verify it builds**

```bash
~/.platformio/penv/bin/pio run -e esp32dev
```

Expected: `SUCCESS`. This is the first fully-green build since Task 1 —
confirms every `LED_PIN` reference is gone and the new wiring compiles.

- [ ] **Step 3: Commit**

```bash
git add src/main.cpp
git commit -m "Wire WiFi indicator callback to on-screen dot in main.cpp"
```

---

### Task 6: Flash, verify on hardware, and record findings

This task is manual — it requires the physical board over USB, which this
agent cannot access. Run each check yourself and report back what you see;
findings get folded into `CLAUDE.md` afterward.

**Files:**
- Modify: `CLAUDE.md` (after verification, to document this board's quirks
  the same way the ILI9341 board's quirks are documented today)

- [ ] **Step 1: Flash the board**

```bash
~/.platformio/penv/bin/pio run -e esp32dev -t upload
~/.platformio/penv/bin/pio device monitor
```

- [ ] **Step 2: Check display colors**

Confirm the Claude/Grok/Settings screens show correct, non-inverted,
non-color-swapped colors (green progress bars actually look green, not
orange/blue-shifted). If colors are wrong, that's the
`-DTFT_RGB_ORDER=TFT_BGR` / `-DTFT_INVERSION_ON` flags from Task 1 — report
which one(s) need to be flipped or removed and it'll be a one-line follow-up
to `platformio.ini`.

- [ ] **Step 3: Check orientation and touch mapping**

Confirm the display shows landscape 320×240 (not portrait or upside-down)
with `_tft.setRotation(3)` (unchanged from `Renderer::init`). Tap the
navigation zones, brightness +/-, interval buttons, LED toggle, and reboot
button on the Settings screen (all previously covered by the touch-mirroring
quirk documented in `CLAUDE.md`) and confirm each does what it visually
says. If tapping feels mirrored or offset, that confirms this board's touch
x-axis behaves differently from the old board's and `TouchRouter.cpp`'s
`319 - x` mirroring math needs re-deriving for this hardware.

- [ ] **Step 4: Check backlight**

Confirm the brightness +/- buttons on the Settings screen visibly dim/
brighten the display via GPIO27.

- [ ] **Step 5: Check the on-screen WiFi indicator**

Power-cycle the board (or temporarily use a wrong WiFi password to force a
retry loop) and confirm the small dot in the top-right corner blinks
while connecting and disappears/goes solid appropriately once connected.
Confirm toggling "LED: ON/OFF" on the Settings screen suppresses it.

- [ ] **Step 6: Record findings in `CLAUDE.md`**

Once the above is verified (with any needed one-line fixes to
`platformio.ini` or `TouchRouter.cpp` made and committed separately), add a
short section to `CLAUDE.md` alongside the existing "Critical hardware
quirks" section, documenting this board's actual (not assumed) rotation,
color-flag, and touch-mirroring behavior, so a future session doesn't have
to rediscover it.

- [ ] **Step 7: Commit**

```bash
git add CLAUDE.md
git commit -m "Document ESP32-32E CYD board quirks after hardware verification"
```

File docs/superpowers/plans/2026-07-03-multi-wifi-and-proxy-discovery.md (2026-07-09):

# Multi-Network WiFi + Automatic Proxy Discovery Implementation Plan

> **For agentic workers:** REQUIRED SUB-SKILL: Use superpowers:subagent-driven-development (recommended) or superpowers:executing-plans to implement this plan task-by-task. Steps use checkbox (`- [ ]`) syntax for tracking.

**Goal:** Let the ESP32 firmware try up to 3 pre-defined WiFi networks in priority order, and automatically discover the proxy server's IP on whichever network it lands on (instead of a hardcoded IP), with NVS caching for fast subsequent boots and a rescan-before-restart failure path.

**Architecture:** All new logic lives in `DataFetcher` (WiFi connection loop over a credential array; proxy discovery via NVS-cached IP + subnet scan with a cheap TCP-probe-then-JSON-validate two-phase check). `main.cpp` only changes how it constructs `DataFetcher` and how it reacts to repeated fetch failures. `Renderer` and `TouchRouter` are untouched.

**Tech Stack:** Arduino/ESP32 (arduino-esp32 core), `WiFi.h`, `WiFiClient`, `HTTPClient`, `Preferences.h` (built into the core, no new `lib_deps`), `ArduinoJson` (already a dependency).

## Global Constraints

- Proxy port stays fixed at 3000 (matches `claude_monitor_be/src/config-store.js` default). Known limitation, not handled: if the port is ever changed in the Electron app's Settings, the ESP32 firmware's `PROXY_PORT` constant must be updated and reflashed.
- Subnet scan assumes a `/24` network (per spec) — iterates host octet 1-254 off `WiFi.localIP()`'s first three octets. Does not attempt to generalize to other mask sizes.
- `validateProxy()` must accept both valid response shapes from the real server: `200` with `claude`/`grok` keys, and `503` with an `error` key (the server returns this before its first poll completes — see `claude_monitor_be/src/server-manager.js:15-22`). Anything else is "not the proxy."
- No unit test infrastructure exists in this project (all logic is hardware-coupled). Verification per task is: does it compile (`pio run`), and — for the final task — manual on-hardware checks.
- LEDC/WiFi-reconnect/HTTP-reuse/log-suppression quirks documented in `CLAUDE.md` must still be respected (they aren't touched by this plan, but don't reintroduce `WiFi.reconnect()` or drop `http.setReuse(false)`).

---

## File Structure

- **Modify `src/Types.h`**: add `WifiCredential` struct.
- **Modify `src/Config.h`**: add `PROXY_PORT`, `WIFI_CONNECT_TIMEOUT_MS`, `PROXY_PROBE_TIMEOUT_MS`, `PROXY_VALIDATE_TIMEOUT_MS`.
- **Modify `src/DataFetcher.h`**: constructor takes `(const WifiCredential* networks, size_t networkCount, uint16_t proxyPort)`; new private helpers for connection-per-network, IP caching, validation, scanning, resolution; new public `recoverProxy()`.
- **Modify `src/DataFetcher.cpp`**: implement all of the above.
- **Modify `src/main.cpp`**: declare the WiFi network array (3 entries — 1 real, 2 placeholders the user fills in), drop `proxyUrl`, update `DataFetcher` construction, update the 5-failure branch in `loop()` to call `recoverProxy()` before restarting.

---
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

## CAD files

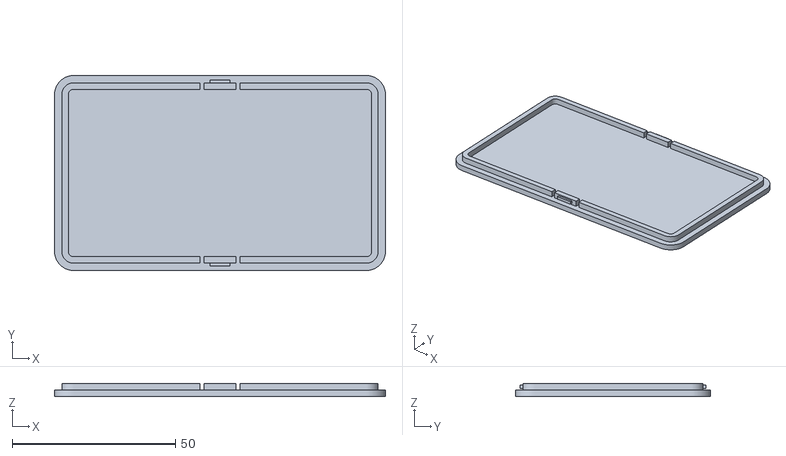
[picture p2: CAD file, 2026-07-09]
cad/stl/case_lid.stl
101.4 x 59.7 x 4.10

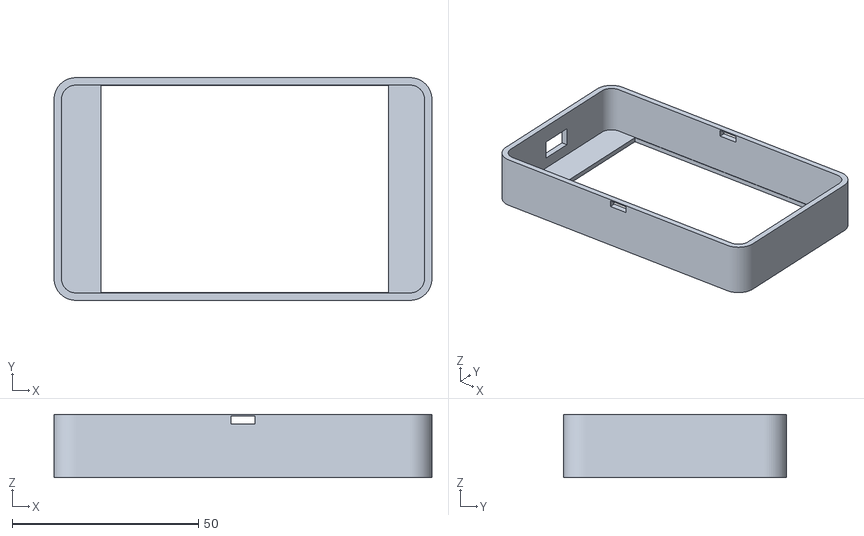
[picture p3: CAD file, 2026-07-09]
cad/stl/case_body.stl
101.4 x 59.7 x 17.0

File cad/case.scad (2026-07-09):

// ============================================================
// Claude Monitor enclosure — LCDWIKI E32R32P (3.2" ESP32-32E CYD)
// + Akyga LP405090 LiPo battery
//
// Two printable parts, selected by the PART variable at the
// bottom of this file: "body" and "lid". Render/export each
// separately (F6 -> Export as STL in OpenSCAD, or the CLI calls
// used to generate cad/stl/*.stl).
//
// Board dimensions are from LCDWIKI's
// E32R32P_E32N32P_Specification_V1.0.pdf, sections 3.2/3.4/4.1/5.1.
// Battery dimensions are user-measured (Akyga LP405090).
// Everything is a variable — re-measure your actual hardware and
// tweak the numbers below before printing if anything doesn't
// match.
// ============================================================

/* [Board — datasheet sec 5.1 / 3.4, landscape orientation (long
   edge horizontal), matching this project's default rotation 3.
   Hole spacing cross-checked against LCDWIKI's E32N32P_Size.pdf
   (same PCB, no-touch sibling SKU, clearer print of the same
   drawing) — that copy states the short-axis hole spacing in
   plain text as "48.00(HOLE)", not the 54.64 originally used here
   (54.64 was actually "(RTP OD)", a touch-panel outline dimension
   misread off the busier E32R32P sheet). ] */
pcb_l        = 93.70;  // PCB long-edge length          (sec 5.1 "93.70(PCB)")
pcb_w        = 55.04;  // PCB short-edge width           (sec 5.1 "55.04(PCB)")
pcb_corner_r = 3.50;   // PCB corner radius              (sec 5.1 "4-R3.50")
// hole_l/hole_w/hole_d: reference only, not used by any geometry below — this
// design has no corner standoffs/screws (see the note near case_body() for
// why), so these just document the real hardware for whoever revisits this.
hole_l       = 86.70;  // mounting-hole pattern, long axis  (sec 5.1 "86.70(HOLE)")
hole_w       = 48.00;  // mounting-hole pattern, short axis (E32N32P_Size.pdf "48.00(HOLE)")
hole_d       = 3.50;   // mounting hole diameter          (sec 5.1 "4-Ø3.20")
stack_d      = 5.70;   // PCB-back-to-glass-front stack depth (sec 3.4 "Module...5.70(D)")
pcb_thick    = 1.60;   // bare PCB thickness (stack breakdown 1.60+1.20+2.40+0.50=5.70)
back_comp_h  = 2.00;   // tallest back-side SMD component height (sec 5.1 side view "5.09 Max(SMD)")

/* [Screen window — sec 3.2/5.1]
   Sized to the LCD BACKLIGHT/glass MODULE footprint (77.70 x 55.04, per
   E32N32P_Size.pdf) on BOTH axes, not the smaller active-pixel area
   (64.80 x 48.60). The module is centered on the PCB in the long axis
   (93.70-77.70=16.00, i.e. exactly 8.00mm margin both ends — matches that
   drawing's separately-printed "8.00" label); in the short axis the module
   (55.04) is exactly pcb_w — flush edge-to-edge, zero margin on the PCB
   itself. This still leaves a real bezel because the front wall is solid
   out to the case's OUTER edge (out_w), not just the cavity edge (in_w) —
   with screen_reveal_extra=0.2 the window ends up ~2.15mm inside out_w,
   plenty for a clean frame. Either way, the smaller active area nests
   entirely inside the module footprint on both axes, so every active pixel
   is still fully exposed. The active area itself is NOT centered within the
   module on the long axis (11.50mm from one end, 17.40mm from the other,
   because of the FPC tail) — but that only matters if you want the window
   to hug the pixels tightly; using the module size instead sidesteps that
   asymmetry entirely. */
screen_w            = 76.75; // LCD BL (glass module), long axis  ("77.70±0.2(LCD BL)")
screen_h            = 55.04; // LCD BL (glass module), short axis — equals pcb_w exactly
screen_r_margin     = 8.00;  // module offset from PCB edge, symmetric both ends
screen_reveal_extra = 0.2;   // extra reveal so the bezel doesn't clip the glass edge

// IMPORTANT: with the corrected hole_w=48.00, the mounting-hole centers
// (±24.00mm) fall *inside* the screen active area's own half-height
// (±24.30mm) — the datasheet's own numbers give the screw holes essentially
// zero (or negative, once ±0.2 tolerance is considered) clearance from the
// visible glass. There is no boss diameter, however small, that avoids the
// window at that exact position — see standoffs() below for how this is
// actually handled (short answer: it isn't a mounting point on this design).

/* [USB-C cutout — sec 4.1 interface photo: Type-C sits on the
   LEFT short edge, vertically centered (derived from sec 5.1's
   13.92/13.60/13.92 left-edge spacing, which sums symmetrically
   around pcb_w/2). The connector is mounted on the PCB's BACK
   (component) side, i.e. it only exists at z >= z_pcb_back and
   extends further in (larger z) from there — usbc_z0 must be >= 0.
   A previous value of -1 put the cutout 1mm in front of z_pcb_back,
   inside the LCD-module/PCB stack itself, which is too close to the
   screen side. Height is still an estimate — verify against your
   physical board and adjust if it's off. ] */
usbc_w  = 11.0;
usbc_h  = 6.0;
usbc_z0 = -2;    // offset added to z_pcb_back (see derived section) — must be >= 0

/* [Battery — Akyga LP405090, user-measured] */
batt_l = 94;
batt_w = 50;
batt_t = 3.0;

/* [Fit & print tuning] */
clearance    = 0.35; // per-side gap around the PCB inside its cavity (XY footprint only —
                      // see batt_z_slack below for the battery's own, separate tolerance)
wall         = 2.0;  // structural wall thickness
front_wall   = 1.5;  // front bezel thickness (thinner: it's mostly cut away by the screen window)
skirt_h      = 2.1;  // lid skirt engagement depth into the case body. A 2mm overall depth cut
                      // was needed; the first attempt took the whole 2mm out of skirt_h alone
                      // (3.5->1.5), which is the wrong place — it's the one thing that actually
                      // holds the lid on. Rebalanced: most of the cut now comes out of slack
                      // that wasn't doing much (see the shrunk comp-to-battery gap and
                      // batt_z_slack below, plus the final case_h margin), so skirt_h only
                      // drops to 2.1 instead of 1.5 — tab thickness (skirt_h*0.5) is 1.05mm
                      // instead of 0.75mm for the same total case_h.
fit_gap      = 0.25; // skirt-to-cavity clearance (loosen if the lid is too tight on your printer)
lid_thick    = 2.0;  // lid back-plate thickness
tab_w        = 6;    // snap-tab width
tab_reach    = 0.8;  // how far the snap tab bump projects past the skirt face
batt_z_slack = 0.2;   // battery-bay depth tolerance — deliberately a separate variable from
                      // `clearance` above: they used to be the same value reused for two
                      // unrelated things, so tightening the PCB's XY fit would have silently
                      // made the case_h computation change too (via z_batt_back). Trimmed from
                      // 0.35 to 0.2 as part of the depth-reduction rebalance (see skirt_h).
batt_l_extra = 3.0;   // extra cavity length (X axis) beyond what the PCB itself needs, purely
                      // to give the battery bay room — at batt_l=94 vs the PCB-driven in_l
                      // (~94.4 with just `clearance`), there was only ~0.4mm to spare, not
                      // enough to actually place the battery + its connector/wire.
                      // NOT added to in_w: batt_w=50 already clears in_w comfortably.
                      // Note this widens the case uniformly front-to-back (same cross-section
                      // the whole depth), so the front bezel ends up with ~1.5mm more margin
                      // on each end too — cosmetic only, doesn't touch the screen window math
                      // below (that's still centered on pcb_l, not in_l).
$fn = 64;

// ---- derived (don't hand-edit these — they follow from the above) ----
in_l  = pcb_l + 2*clearance + batt_l_extra;
in_w  = pcb_w + 2*clearance;
in_r  = pcb_corner_r + clearance;

out_l = in_l + 2*wall;
out_w = in_w + 2*wall;
out_r = in_r + wall;

lcd_module_gap = stack_d - pcb_thick;          // LCD module footprint in front of the PCB (RTP+glass+tape)
z_pcb_front  = front_wall + lcd_module_gap;    // PCB front (copper/RTP side) surface — flush LCD glass sits right at the front wall
z_pcb_back   = z_pcb_front + pcb_thick;        // PCB back (component) surface
z_comp_tip   = z_pcb_back + back_comp_h;       // tallest back-side component tip
z_batt_front = z_comp_tip + 0.3;               // clearance gap before battery bay (trimmed from
                                                // 0.6 as part of the depth-reduction rebalance)
z_batt_back  = z_batt_front + batt_t + batt_z_slack;
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

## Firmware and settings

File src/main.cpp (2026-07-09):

#include <Arduino.h>
#include <WiFi.h>
#include "esp_log.h"
#include "esp_system.h"
#include "Config.h"
#include "Types.h"
#include "DataFetcher.h"
#include "Renderer.h"
#include "NvsConfig.h"
#include "TouchRouter.h"
#include "Battery.h"

const WifiCredential wifiNetworks[] = {
  { "TP-Link_4400", "Chippo545454A" },
  { "at300", "m4ruAvub" },
};

AppState    state;
UsageData   data      = {};
DataFetcher fetcher(wifiNetworks, sizeof(wifiNetworks) / sizeof(wifiNetworks[0]), PROXY_PORT);
Renderer    renderer;
Battery     battery;
TouchRouter touch(renderer.tft());

unsigned long lastFetch = 0;

void wifiIndicator(bool on) {
  renderer.drawWifiIndicator(on);
}

// Diagnostic: logs the ESP-IDF disconnect reason code so a dropped
// connection can be told apart from AP-side vs. RF-side vs. auth causes.
// See esp_wifi_types.h for the full reason-code list.
void logWifiEvent(WiFiEvent_t event, WiFiEventInfo_t info) {
  switch (event) {
    case ARDUINO_EVENT_WIFI_STA_DISCONNECTED:
      Serial.printf("[wifi] disconnected, reason=%d\n", info.wifi_sta_disconnected.reason);
      break;
    case ARDUINO_EVENT_WIFI_STA_CONNECTED:
      Serial.printf("[wifi] connected to %.*s\n", info.wifi_sta_connected.ssid_len,
                    (const char*)info.wifi_sta_connected.ssid);
      break;
    case ARDUINO_EVENT_WIFI_STA_GOT_IP:
      Serial.printf("[wifi] got IP, RSSI=%d dBm\n", WiFi.RSSI());
      break;
    default: break;
  }
}

// Common anode RGB LED — LOW turns a channel ON, HIGH turns it off.
void rgbLed(LedSignal signal) {
  bool r = false, g = false, b = false;
  switch (signal) {
    case LedSignal::BlueBlinkOn: b = true; break;
    case LedSignal::Red:         r = true; break;
    case LedSignal::Green:       g = true; break;
    case LedSignal::BlueBlinkOff:
    case LedSignal::Off:         break;
  }
  digitalWrite(LED_RED_PIN,   r ? LOW : HIGH);
  digitalWrite(LED_GREEN_PIN, g ? LOW : HIGH);
  digitalWrite(LED_BLUE_PIN,  b ? LOW : HIGH);
}

#if CM_DEBUG_POWER
// Diagnostic: names the boot cause, so a watchdog reset caused by the
// loop() yield or CPU-frequency change would be visible in the serial log
// instead of looking like a silent power-cycle.
const char* resetReasonName(esp_reset_reason_t reason) {
  switch (reason) {
    case ESP_RST_POWERON:   return "POWERON";
    case ESP_RST_EXT:       return "EXT";
    case ESP_RST_SW:        return "SW";
    case ESP_RST_PANIC:     return "PANIC";
    case ESP_RST_INT_WDT:   return "INT_WDT";
    case ESP_RST_TASK_WDT:  return "TASK_WDT";
    case ESP_RST_WDT:       return "WDT";
    case ESP_RST_DEEPSLEEP: return "DEEPSLEEP";
    case ESP_RST_BROWNOUT:  return "BROWNOUT";
    case ESP_RST_SDIO:      return "SDIO";
    default:                return "UNKNOWN";
  }
}
#endif // CM_DEBUG_POWER

void setup() {
  Serial.begin(115200);
  esp_log_level_set("*", ESP_LOG_NONE);
#if CM_DEBUG_POWER
  Serial.printf("[boot] reset reason=%s\n", resetReasonName(esp_reset_reason()));
#endif

  // This app is I/O-bound (SPI, WiFi, timers), not compute-bound, so 240MHz
  // is unused headroom that costs battery. WiFi requires >=80MHz; SPI/touch
  // clocks come from the fixed 80MHz APB bus and are unaffected by this.
  setCpuFrequencyMhz(80);
#if CM_DEBUG_POWER
  Serial.printf("[boot] cpu freq=%u MHz\n", getCpuFrequencyMhz());
#endif

  pinMode(LED_RED_PIN,   OUTPUT);
  pinMode(LED_GREEN_PIN, OUTPUT);
  pinMode(LED_BLUE_PIN,  OUTPUT);
  digitalWrite(LED_RED_PIN,   HIGH);
  digitalWrite(LED_GREEN_PIN, HIGH);
  digitalWrite(LED_BLUE_PIN,  HIGH);

  fetcher.setIndicatorCallback(wifiIndicator);
  fetcher.setRgbCallback(rgbLed);
  WiFi.onEvent(logWifiEvent);
  // Default modem-sleep power save causes missed beacons -> reason=200
  // disconnect storms on this hardware; disable it before the first begin().
  WiFi.mode(WIFI_STA);
  WiFi.setSleep(false);

  state.rotation = NvsConfig::loadRotation(3);
  renderer.init(state.rotation, state.brightness);
  renderer.showConnecting();

  battery.init();
  int pct = battery.readPercent();
  renderer.setBattery(pct, battery.isCharging());

  if (fetcher.connect()) {
    bool ok = false;
    for (int i = 0; i < 3 && !ok; i++) {
      if (i > 0) delay(2000);
      ok = fetcher.fetch(data);
    }
    if (ok) {
      renderer.update(state.screen, data, /*fullRedraw=*/true);
      state.needsFullRedraw = false;
      lastFetch = millis();
    } else {
      renderer.showServerError();
      state.needsFullRedraw = true;
      lastFetch = 0;
    }
  } else {
    renderer.showWifiFailed();
    state.needsFullRedraw = true;
    lastFetch = millis() - 30000;
  }
}

#if CM_DEBUG_POWER
// Diagnostic: prints loop iterations/sec every 5s so the effect of the
// delay(10) yield and CPU-frequency change can be seen directly, and to
// confirm the loop never stalls.
void logLoopRate() {
  static unsigned long lastLogMs = 0;
  static unsigned long iterations = 0;
  iterations++;
  unsigned long now = millis();
  if (now - lastLogMs >= 5000) {
    Serial.printf("[loop] %lu iterations / %lus (%.1f Hz)\n",
                  iterations, (now - lastLogMs) / 1000, iterations * 1000.0f / (now - lastLogMs));
    iterations = 0;
    lastLogMs = now;
  }
}
#endif // CM_DEBUG_POWER

void loop() {
#if CM_DEBUG_POWER
  logLoopRate();
#endif
  fetcher.tick();
  if (state.screen == 0) renderer.tickSprite();

  Event touchEvent = touch.poll(state.screen);
#if CM_DEBUG_POWER
  if (touchEvent != Event::None) {
    // Diagnostic: confirms touch presses still register promptly with the
    // delay(10) yield in place below.
    Serial.printf("[touch] event=%d at t=%lu\n", (int)touchEvent, millis());
  }
#endif

  switch (touchEvent) {
    case Event::NavForward:
      if (state.screen == 2) state.rebootArmedAt = 0;
      state.screen = (state.screen + 1) % 3;
      renderer.switchTo(state.screen, data, state.brightness, state.fetchInterval, state.ledEnabled);
      state.needsFullRedraw = false;
      break;
    case Event::NavBack:
      if (state.screen == 2) state.rebootArmedAt = 0;
      state.screen = (state.screen + 2) % 3;
      renderer.switchTo(state.screen, data, state.brightness, state.fetchInterval, state.ledEnabled);
      state.needsFullRedraw = false;
      break;
    case Event::BrightnessUp:
      state.brightness = min(255, (int)state.brightness + 20);
      ledcWrite(BL_CHANNEL, state.brightness);
      renderer.updateBrightnessBar(state.brightness);
      break;
    case Event::BrightnessDown:
      if (state.brightness > 20) state.brightness -= 20;
      ledcWrite(BL_CHANNEL, state.brightness);
      renderer.updateBrightnessBar(state.brightness);
      break;
    case Event::Interval30s:
      state.fetchInterval = 30000;
      renderer.updateIntervalButtons(state.fetchInterval);
      break;
    case Event::Interval60s:
      state.fetchInterval = 60000;
      renderer.updateIntervalButtons(state.fetchInterval);
      break;
    case Event::Interval120s:
      state.fetchInterval = 120000;
      renderer.updateIntervalButtons(state.fetchInterval);
      break;
    case Event::ToggleLed:
      state.ledEnabled = !state.ledEnabled;
      fetcher.setLedEnabled(state.ledEnabled);
      renderer.updateLedToggle(state.ledEnabled);
      break;
    case Event::Reboot:
      if (state.rebootArmedAt != 0 && millis() - state.rebootArmedAt < 2000) {
        renderer.showRebooting();
        delay(300);
        ESP.restart();
      } else {
        state.rebootArmedAt = millis();
        renderer.updateRebootIcon(true);
      }
      break;
    case Event::CycleRotation: {
      state.rebootArmedAt = 0; // switchTo redraws the reboot icon disarmed; keep state in sync
      static const uint8_t order[4] = {3, 0, 1, 2};
      int idx = 0;
      for (int i = 0; i < 4; i++) if (order[i] == state.rotation) { idx = i; break; }
      state.rotation = order[(idx + 1) % 4];
      renderer.setRotation(state.rotation);
      NvsConfig::saveRotation(state.rotation);
      renderer.switchTo(state.screen, data, state.brightness, state.fetchInterval, state.ledEnabled);
      state.needsFullRedraw = false;
      break;
    }
    case Event::Recalibrate:
      state.rebootArmedAt = 0; // recalibrate + switchTo redraw the reboot icon disarmed
      renderer.recalibrate(state.rotation);
      renderer.switchTo(state.screen, data, state.brightness, state.fetchInterval, state.ledEnabled);
      state.needsFullRedraw = false;
      break;
    default: break;
  }

  if (state.screen == 2 && state.rebootArmedAt != 0 && millis() - state.rebootArmedAt > 2000) {
    state.rebootArmedAt = 0;
    renderer.updateRebootIcon(false);
  }

  if (millis() - lastFetch > state.fetchInterval) {
    int pct = battery.readPercent();
    renderer.setBattery(pct, battery.isCharging());
    if (fetcher.fetch(data)) {
      renderer.update(state.screen, data, state.needsFullRedraw);
      state.needsFullRedraw = false;
    } else if (fetcher.consecutiveFailures() >= 5) {
      if (!fetcher.recoverProxy()) {
        ESP.restart();
      }
    }
    lastFetch = millis();
  }

  // Yield to the FreeRTOS idle task so the CPU can idle (WFI) between
  // iterations instead of spinning at full clock forever — see battery
  // review, 2026-07-05. 10ms keeps touch feeling instant (~100Hz polling)
  // while giving the idle task a chance to run.
  delay(10);
}

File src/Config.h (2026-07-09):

#pragma once

// Verbose serial logging for the loop-yield / CPU-frequency power tuning
// (boot reset reason + CPU freq, loop iteration rate, touch event timing).
// Off by default so normal runs stay quiet; enable with
// `-DCM_DEBUG_POWER=1` in platformio.ini's build_flags when you need to
// re-verify the power changes on hardware.
#ifndef CM_DEBUG_POWER
#define CM_DEBUG_POWER 0
#endif

#define TFT_BL_PIN 27
#define BL_CHANNEL 0
#define BL_FREQ    5000
#define BL_RES     8

// Onboard RGB status LED (common anode — LOW turns a channel ON).
#define LED_RED_PIN   22
#define LED_GREEN_PIN 16
#define LED_BLUE_PIN  17

// Proxy discovery
#define PROXY_PORT 3000
#define WIFI_CONNECT_TIMEOUT_MS 8000
#define PROXY_PROBE_TIMEOUT_MS 150
#define PROXY_VALIDATE_TIMEOUT_MS 1000

// Battery level sensing — onboard 100K/100K divider on GPIO34.
// See docs/superpowers/specs/2026-07-05-battery-level-display-design.md
#define BAT_ADC_PIN      34
#define BAT_SAMPLE_COUNT 32     // raised from 8 on 2026-07-05: on-device logging at 120s
                                // fetch interval showed +-4mV reading-to-reading noise at
                                // ~65% SoC, comparable to the real per-interval charge
                                // signal — more averaging shrinks that noise floor.
#define BAT_MIN_MV       3300  // maps to 0%
#define BAT_MAX_MV       4200  // maps to 100%
#define BAT_LOW_PCT      15    // battery icon renders red at/below this

// Retuned 2026-07-05 from on-device diagnostic logging (see git history /
// conversation): at ~65% SoC on a 120s fetch interval, real consecutive-
// reading deltas while charging were only 1-4mV — the original 15mV
// threshold never triggered because every reading looked "flat" to it.
//
// KNOWN LIMITATION, confirmed on hardware, not fixed further by design
// choice (see conversation history): esp_adc_cal_raw_to_voltage() returns
// 1mV resolution, doubled for the divider, so readings are quantized to
// 2mV steps. At slow charge rates (observed: <1mV/tick average, well under
// one quantization step) most individual ticks read delta=0 with only
// occasional non-consecutive +2/+4mV jumps once drift crosses a
// quantization boundary. Because BAT_CHG_RISE_STREAK requires *consecutive*
// rising ticks, no threshold value in this scheme can reliably detect
// charging in that slow-rate regime — the jumps are real but never
// back-to-back. A fix would require comparing against a reading several
// ticks back instead of just the previous one (a bigger design change),
// which was considered and deliberately not pursued. Practical effect: the
// charging bolt may fail to appear during slow/near-full charging phases
// even though charging is genuinely happening — accepted as-is.
#define BAT_CHG_RISE_MV     4   // mV delta beyond which a reading counts as "rising"/"falling" (else "flat")
#define BAT_CHG_RISE_STREAK 3   // consecutive rising reads required to enter "charging"
#define BAT_CHG_FALL_STREAK 2   // consecutive falling reads required to exit "charging"

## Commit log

2026-06-20 Redesign Claude/Grok/Settings screens with buttons and a header sprite
    Replace plain text nav links with bordered button widgets, add a pixel-art
    mascot and bold title to the Claude header, move percentage labels next to
    pills instead of stacked numbers, and format long reset times as "Xh Ym".
    Also enable LOAD_GFXFF for the new free font.
2026-06-26 Add LED on/off toggle to settings screen
    Lets users disable the onboard status LED blinking during WiFi connect/reconnect.
2026-07-03 Add design spec for ESP32-32E CYD board support
    Documents the pin mapping for the new Sunton-clone display board and
    the plan to replace the physical status LED with an on-screen
    indicator, since the new board's fixed pinout claims GPIO2 (LED) and
    GPIO14 (backlight PWM).
2026-07-03 Switch build to ST7789P3 driver and ESP32-32E CYD board pinout
2026-07-03 Drop LED_PIN, move backlight to GPIO27 for ESP32-32E CYD board
2026-07-03 Replace DataFetcher's direct LED GPIO blink with an indicator callback
2026-07-03 Wire WiFi indicator callback to on-screen dot in main.cpp
2026-07-03 Vendor TFT_eSPI locally with LCDWIKI's ST7789P3 init sequence
    The registry copy of bodmer/TFT_eSPI ships a stock User_Setup.h that
    unconditionally #defines its own pins/driver, silently overriding this
    project's platformio.ini build_flags (confirmed via compiler
    "redefined" warnings) — the firmware was actually still running with
    the old ILI9341 board's pin config the whole time despite looking
    correctly configured.
    Vendoring locally lets us both fix that (see next commit, which adds
    -DUSER_SETUP_LOADED=1) and swap in the panel manufacturer's documented
    ST7789_Init.h replacement, which the vendor's own setup instructions
    require: the stock TFT_eSPI ST7789 init table doesn't bring this exa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
2026-07-03 Fix ST7789 pinout override, touch calibration, and touch mapping
    Three real bugs found during hardware bring-up on the physical board:
    - platformio.ini's TFT_eSPI pin/driver build_flags were being silently
    overridden by the vendored library's default User_Setup.h (unguarded
    #define, confirmed via "redefined" compiler warnings) — the firmware
    was still built for the old ILI9341 board's pins the whole time.
    Fixed with -DUSER_SETUP_LOADED=1, which stops User_Setup_Select.h
    from including that file at all. Also matched the vendor's SPI
    frequency (80MHz) and flash mode (DIO) from their reference config.
    - This physical touch panel's raw XPT2046 ADC range never matched
    TFT_eSPI's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
    [main.cpp]
2026-07-03 Document ESP32-32E CYD board quirks after hardware verification
    Records what was actually found flashing and testing the physical
    board: the TFT_eSPI User_Setup.h override bug, the need for the
    vendor's ST7789 init sequence, real touch calibration values, and the
    non-inverted touch axis on this board (vs main's ILI9341 quirk).
2026-07-03 Increase spacing between UI elements on all screens
    The larger physical screen made the original tight layout feel
    cramped despite identical 320x240 resolution. Widened gaps between
    sections on Claude/Grok (more headroom, only two rows each) and made
    more modest increases on Settings (four rows plus nav, less room to
    spare). Touch zones in TouchRouter.cpp updated to match the new
    button positions; verified on hardware.
    This branch only — main's ILI9341 board keeps the original layout.
2026-07-03 Add AnimatedSprite class and mascot pixel-art data
    Not yet wired into Renderer — standalone, compile-checked only.
2026-07-03 Wire AnimatedSprite into Renderer, remove static header sprite
2026-07-03 Fix display tearing in sprite redraw by batching into one SPI transaction
    draw() was issuing the lane-clear fillRect plus one fillRect per pixel cell
    (~40-90 calls) each as its own independent SPI transaction. Between calls,
    the ST7789's own refresh could read out a partially-updated frame, showing
    as a torn/black wedge across the sprite. Wrapping the whole redraw in
    tft.startWrite()/endWrite() batches it into one atomic transaction.
2026-07-03 Composite sprite into one pushImage() call instead of per-cell fillRect()
    The startWrite()/endWrite() batching in the previous commit didn't fix the
    tearing (confirmed on hardware) because it only prevents other SPI masters
    from interrupting the bus — it does nothing about the ST7789's own internal
    refresh racing a write that's still spread across ~40-90 separate
    window-set-then-stream command sequences (one fillRect per pixel cell).
    Build each frame into a local 30x36 pixel buffer and push it with one
    pushImage() call, so a redraw is one fillRect (lane clear) + one pushImage
    (whole sprite) instead of dozens of tiny transactions — far less time for
    the panel's refresh to land mid-sprite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
2026-07-03 Fix color corruption from pushImage() not byte-swapping like fillRect() does
    The pushImage() consolidation introduced a color bug: its raw pixel path
    (pushPixels() with default _swapBytes=false, confirmed in
    Processors/TFT_eSPI_ESP32.c) writes buffer bytes as-is, unlike fillRect()'s
    pushBlock() which always byte-swaps internally. color565() returns
    host-endian values, so the buffer needs pre-swapped colors to match the
    wire's byte order — swapping once per color when building the buffer keeps
    the fast raw burst-write path instead of switching to per-pixel writes via
    setSwapBytes(true).
2026-07-03 Fix black-flash root cause: stop pre-clearing a wide lane on every redraw
    Both previous fix attempts (batching into one SPI transaction, then
    consolidating to one pushImage() call) targeted a hardware-timing-race
    theory, and neither changed the on-hardware symptom at all — a strong
    signal the race theory was wrong. New information from testing: the flash
    happens on every idle-animation frame swap, is fully deterministic (same
    shape every time), and moves with the sprite rather than sitting at a fixed
    screen location — none of which fit a stochastic hardware race, but all of
    which fit a much simpler explanation: draw() was unconditionally painting
    the entire 115px-wide lane black as a sep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
2026-07-03 Clear only the exposed sliver of the sprite's old footprint, not the whole box
    Since the last fix, draw() still cleared the entire previous 30x36 footprint
    whenever the sprite moved, including the part that overlaps the new
    position — repeating the same "black, then color" step on a smaller scale,
    which is consistent with the reported rare residual tearing during
    patrol movement. Only the non-overlapping edge (typically a few px, since
    per-tick movement is small) actually needs clearing; the overlapping bulk
    gets its correct final color directly from pushImage().
2026-07-03 Document the sprite tearing root cause and pushImage byte-swap gotcha
    Records what actually fixed the animated-mascot tearing bug (a
    deterministic "clear a wide area, then redraw" step on every redraw — not
    an SPI timing race, which two earlier attempts wrongly assumed) and the
    pushImage()-vs-fillRect() byte-swap difference that caused a color
    regression along the way, so future TFT_eSPI drawing code on this board
    doesn't repeat either mistake.
2026-07-03 Stop percentage-text clear rect from clobbering the pill's left edge
    updateClaude()'s partial-redraw fillRect for the Session/Weekly percentage
    text spanned x=10-210, overlapping 4px into the "Session"/"Weekly" pill
    drawn at x=206. The full redraw always redraws the pill on top, so it only
    showed up after a value changed and the partial-redraw path ran, leaving a
    permanent notch in the pill's rounded left edge until the next screen switch.
2026-07-03 Drive the onboard RGB LED with WiFi/server status
    This board (per LCDWIKI's E32R32P/E32N32P spec) has a 3-color common-anode
    RGB LED at IO22/16/17 that was previously undriven. Wire it to the same
    status the on-screen WiFi dot already tracks: blue flashing while
    connecting, red when WiFi is down or the proxy server is unreachable, green
    when both are healthy. Gated by the existing Settings "LED: ON/OFF" toggle.
2026-07-03 Add NVS-backed proxy IP caching helpers
    Add three private helper methods to DataFetcher:
    - loadCachedIp(): reads cached proxy IP from NVS
    - saveCachedIp(): writes proxy IP to NVS
    - clearCachedIp(): removes cached IP from NVS
    These will be consumed by Task 5's resolveProxy() and Task 6's
    recoverProxy() to enable persistent caching of discovered proxy
    server IP addresses across power cycles.
2026-07-03 Add subnet-scan proxy discovery and wire it into fetch()
    fetch() now resolves the proxy IP dynamically instead of using the
    hardcoded 192.168.0.58 placeholder from Task 2: resolveProxy() tries
    the cached IP first, falling back to scanForProxy(), which walks the
    local /24 with a cheap TCP-connect probe before running the full
    validateProxy() check.
2026-07-03 Rescan for the proxy before restarting on repeated fetch failures
    [main.cpp]
2026-07-03 Expand WiFi network list to support secondary network
    Added second network credentials (at300) to the wifiNetworks array. This replaces the placeholder approach with actual production credentials for the second network. The array now supports dual-network fallback, allowing the device to attempt connection to TP-Link_4400 first, then fall back to at300 if that is unavailable.
    [main.cpp]
2026-07-03 Log WiFi disconnect reason codes and RSSI for stability diagnosis
    User reports the blue LED (connection-retry indicator) periodically
    flashing while connected to the at300 network. Traced the blink signal
    to its one call site — it only fires when ensureWifi() detects
    WiFi.status() != WL_CONNECTED — so this is a real disconnect/reconnect
    cycle, not a UI issue. No root cause yet; this just gets enough
    evidence (ESP-IDF disconnect reason code, RSSI at reconnect) from the
    next occurrence to tell environmental/RF causes apart from AP-side or
    auth causes before guessing at a fix.
    [main.cpp]
2026-07-04 Apply consistent fonts to shared button/pill helpers and Claude screen
2026-07-04 Shrink VALUE_FONT to 12pt bold to fix tight fit in 32px cards
    The 18pt bold size flagged as clipping-risk in the final review for the
    LED/REBOOT/brightness +/- cards (32px tall) and big percentage values.
2026-07-04 Drop bold weight and shrink title/label/value fonts across all screens
    TITLE_FONT and VALUE_FONT move from FreeSansBold12pt7b to non-bold
    FreeSans9pt7b. LABEL_FONT (FreeSans9pt7b) had no smaller vendored size,
    so labels/captions switch to TFT_eSPI's built-in GLCD font 2 instead,
    which renders noticeably smaller.
2026-07-04 Add design spec for Settings header icon buttons (Reboot/LED)
2026-07-04 Add implementation plan for Settings header icon buttons
2026-07-04 Add reboot-icon drawing and LED-on color helper to Renderer
2026-07-04 Move Reboot/LED to header icon buttons, resize nav buttons
2026-07-04 Move Settings touch zones to match header icon buttons
2026-07-04 Add confirm-tap safety to the header Reboot icon
    [main.cpp]
2026-07-04 Replace header icon glyphs with clearer power symbol and bulb outline
    The broken-ring+arrowhead reboot glyph and the plain-filled-circle LED
    glyph didn't read well at 32px on hardware. Reboot is now a classic
    power symbol (ring with a gap + tick); LED bulb gets a darker outline
    and a proportionally bigger base so it reads as a lamp, not a ball.
2026-07-04 Make WiFi reconnect non-blocking to stop UI freezes on drops
    DataFetcher::ensureWifi() blocked loop() in a delay(250) poll for up
    to 8-16s per reconnect attempt, freezing touch input and the mascot
    animation on every WiFi drop. Replaced with tick(), a step-based state
    machine called every loop() pass that advances the reconnect using
    millis() instead of delay(), so the UI stays responsive while WiFi
    recovers in the background. Also disable modem-sleep power save at
    boot, which was suspected (but not confirmed) to reduce beacon-timeout
    disconnects.
    [main.cpp]
2026-07-05 Add NvsConfig helper for rotation + per-rotation touch calibration
2026-07-05 Add rotation state, derived per-rotation touch calibration, Renderer::setRotation
2026-07-05 Document 4-rotation orientation support and per-rotation calibration
2026-07-05 Clear reboot-arm state on rotation cycle/recalibrate to prevent masked reboot
    [main.cpp]
2026-07-05 Fix portrait touch: use measured calData for rotations 0 and 2
    The derived portrait invert flags were assigned to the wrong rotations
    (0b000 on rot0, 0b110 on rot2 -- exactly reversed). On-device calibrateTouch
    gives rot0={310,3434,426,3415,0b110} and rot2={324,3371,451,3429,0b000},
    a proper 180-degree pair. Rotation 3 keeps its known-good baseline; rotation 1
    stays derived (its calibration run was degenerate). Removes the temporary
    serial calibration harness.
2026-07-05 Add ESP32-32E CYD board-support implementation plan doc
2026-07-05 Add design spec for LP405090 battery support + on-screen level indicator
    Documents the JST-pitch/polarity hardware caveats found in the vendor docs,
    plus the Battery module and Renderer battery-icon design applying SOLID/
    KISS/YAGNI/DRY per review feedback.
2026-07-05 Fix self-review gaps in battery display spec
    Add missing explicit text color/font/datum handling for the percent label,
    and flag an unverified portrait-Settings title/icon collision risk that
    needs hardware verification during implementation.
2026-07-05 Add Battery module for onboard ADC-based charge sensing
2026-07-05 Add Renderer battery icon drawing (not yet wired to any screen)
    - Add _batteryPct member variable (initialized to 100)
    - Add drawBatteryIcon(int pct) private method for rendering battery percentage
    with color logic and progress bar
    - Add setBattery(int pct) public method to cache and display battery reading
    - Battery text uses font 1, MR_DATUM alignment, right-aligned near top-right
    - Icon includes small progress bar and nub indicator
    - Resets text settings to defaults (font 0, TL_DATUM) to maintain renderer convention
2026-07-05 Wire battery icon into all screens and feed live ADC readings
2026-07-05 Add design spec for software-heuristic battery charging indicator
    Documents why no hardware CHRG/VBUS signal is available on this board
    (confirmed against the full WROOM-32E schematic net list), and the
    three-bucket voltage-trend state machine + bolt-overlay rendering chosen
    as the software-only fallback.
2026-07-05 Fix self-review findings in charging-indicator spec
    Bolt's bottom point was landing on drawProgressBar's border row instead
    of the fill interior; corrected coordinates and documented the border/
    interior row math. Corrected "on top of the fill" framing (only true at
    higher percentages). Added testing notes for the two accepted-risk items:
    untuned noise threshold (no on-device data yet) and glitch-read false
    rising deltas.
2026-07-05 Add voltage-trend charging detection to Battery
    Implement three-bucket (rising/flat/falling) streak state machine that infers
    charging state from voltage trends. Adds readMilliVoltsAveraged() and classify()
    private methods; new public isCharging() method reflects state as of the last
    readPercent() call. Constants BAT_CHG_RISE_MV, BAT_CHG_RISE_STREAK,
    BAT_CHG_FALL_STREAK added to Config.h.
2026-07-05 Add charging bolt overlay and wire it through main.cpp (Task 2, folded with caller update)
    Renderer::setBattery/drawBatteryIcon now take a charging bool and draw a
    white bolt inside the battery-icon fill when true. Folds in main.cpp's two
    existing setBattery call sites (setup() and loop()'s fetch-interval block)
    in the same commit rather than a separate dispatch: the signature change
    alone would not compile against the pre-existing one-arg callers, and a
    plan that split the two into separate subagent tasks would have left a
    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
2026-07-05 Address final review Minor findings for charging indicator
    - Document in Config.h that the charging-detection thresholds are
    provisional estimates, not yet measured against real ADC noise.
    - Add a Task 4 step to sanity-check the underlying battery percentage
    against a metered voltage before tuning charging thresholds, since the
    level-indicator feature's own hardware pass is still pending too.
    [Config.h]
2026-07-05 Add missing commit of battery-level-display implementation plan doc
2026-07-05 Retune charging thresholds from real hardware data, document known limit
    Hardware verification (see conversation) showed the original BAT_CHG_RISE_MV
    (15mV) never triggered: real per-tick voltage change during charging was
    only 1-4mV at ~65% SoC. Raised BAT_SAMPLE_COUNT 8->32 to reduce ADC noise
    and lowered BAT_CHG_RISE_MV 15->4 to match, removing the temporary
    diagnostic Serial logging used to gather that data.
    Further testing showed even this doesn't fully solve it: readings are
    quantized to 2mV steps (esp_adc_cal's 1mV resolution x2 for the divider),
    and at slow charge rates most ticks show delta=0 with only occasional,
    non-consecutive +2/+4mV jumps -- the "3 consecutive rising reads"
    re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
    [Config.h]
2026-07-05 Document hardware verification outcome for charging indicator
    Records the real-hardware findings from Task 4: level reading confirmed
    physically correct, charging bolt found to have a structural quantization/
    consecutive-tick limitation not fixable by threshold retuning alone. A
    bigger redesign (lagged-baseline comparison) was considered and declined.
2026-07-05 Yield CPU in loop() and drop clock to 80MHz to reduce battery draw
    loop() previously spun unbounded at 240MHz, never letting the FreeRTOS
    idle task run between iterations. Add delay(10) to yield (~100Hz touch
    poll, imperceptible lag) and drop to 80MHz since this app is I/O-bound
    (SPI/WiFi/timers), not compute-bound. Verified on hardware: stable loop
    cadence, no missed touches, no watchdog resets, fetch/render unaffected.
    Diagnostic logging used to verify this (reset reason, loop rate, touch
    timing) is kept but gated behind CM_DEBUG_POWER (off by default) so it
    can be re-enabled for future verification without re-adding by hand.
    [Config.h, main.cpp]
2026-07-05 Document loop-yield/CPU-frequency battery tuning in CLAUDE.md
    Records why loop() needed a yield, why 80MHz is safe on this board,
    and that CM_DEBUG_POWER exists so it's not rediscovered/re-added ad hoc.
2026-07-09 Add CAD case files and document them in README
    [case.scad, case_body.stl, case_lid.stl]
2026-07-10 docs: add device photo to README
